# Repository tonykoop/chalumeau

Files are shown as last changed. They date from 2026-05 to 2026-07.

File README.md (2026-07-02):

# Chalumeau Family

Status: L2 V5 build-packet candidate. This is a prototype-validation scaffold
with parametric tables, starter CAD/drawings, presentation exports, and
measurement templates, but it is not a validated/build-ready or measured
chalumeau packet.

> Bare-bones readiness packet for a family of single-reed chalumeaux:
> keyless folk-pipe simplicity first, optional handmade two-key metalwork
> second, and a documented path toward clarinet-style register experiments.
> The current repo is a prototype-validation scaffold, not a build-ready or
> measured packet.

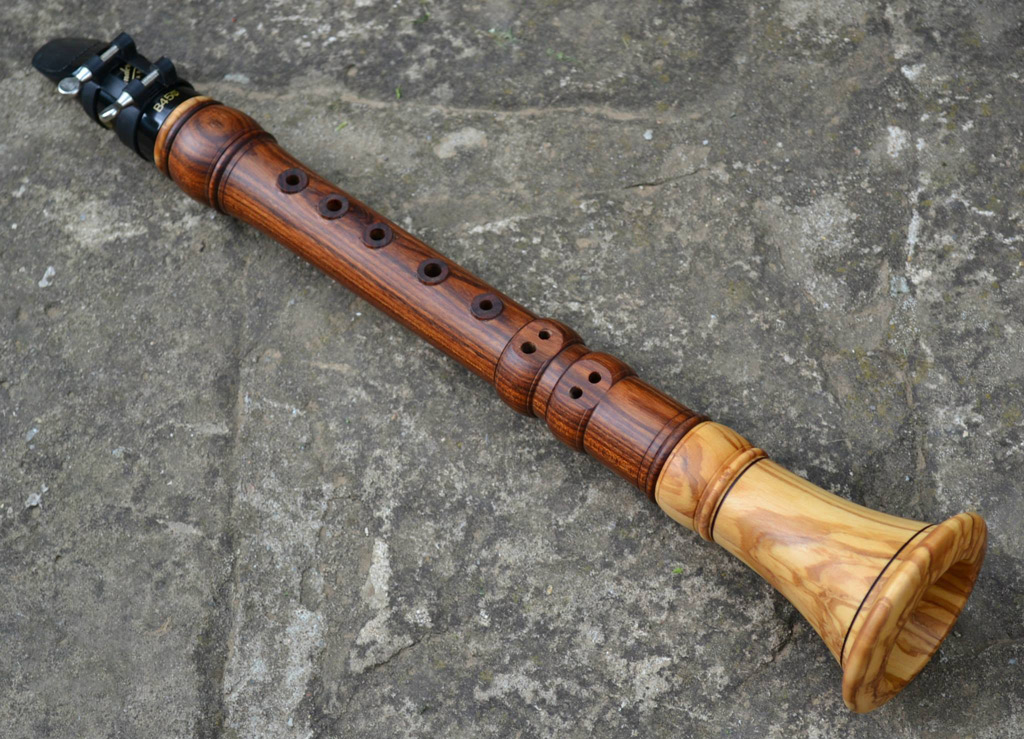
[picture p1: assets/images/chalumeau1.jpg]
Inspiration chalumeau with turned wood body, raised tone-hole collars, black mouthpiece, and flared bell

*Photo/reference instrument by Petr Skalicky / Dudy.eu, from
[dudy.eu/chalumeau.php](https://www.dudy.eu/chalumeau.php). Used here
as an attributed design reference, not as Tony's own build photo.*

## GitHub Repo Metadata

**Description:** Parametric build packet for a handmade chalumeau family,
including stopped-reed acoustics, tone-hole schedules, SolidWorks design
tables, and DIY keywork.

**Suggested topics:** `chalumeau`, `woodwind`, `single-reed`,
`clarinet-history`, `instrument-making`, `parametric-design`,
`solidworks`, `acoustic-modeling`, `cnc-lathe`, `woodworking`,
`music-technology`, `build-packet`

## What this is

This repository now contains a first-pass engineering packet for
designing and prototyping a family of chalumeaux in soprano C, alto G,
tenor C, and bass F. The design is parametric: body length, bore,
tone-hole positions, and optional levers are driven from formulas rather
than hidden one-off dimensions. It is not yet a build-ready or
empirically validated packet; the first soprano prototype still needs
measured reed, mouthpiece, bore, tuning, and response data.

The packet starts from attributed Dudy.eu chalumeau reference photos in
`assets/images/`, Tony's `Musical Instruments.xlsx` workbook, and especially
the reed/bore lessons in the `Great Highland Bagpipe` sheet. The
acoustic model is not copied from Native American style flute K2
corrections. A chalumeau is a cylindrical, single-reed, effectively
stopped pipe, so it gets its own validation loop.

## Family plan

| ID | Variant | Root | Bore ID | Final body L | Blank L | Sections |
| --- | --- | --- | --- | --- | --- | --- |
| CLM-SOP-C4 | Soprano C | C4 | 0.5 | 12.672 | 14.172 | 1 body + mouthpiece + bell |
| CLM-ALT-G3 | Alto G | G3 | 0.625 | 16.939 | 18.439 | 1 body + mouthpiece + bell |
| CLM-TEN-C3 | Tenor C | C3 | 0.75 | 25.483 | 26.983 | 2 body joints + mouthpiece + bell |
| CLM-BAS-F2 | Bass F | F2 | 0.875 | 38.32 | 39.82 | 3 body joints + mouthpiece + bell |

The recommended build order is `CLM-SOP-C4` first, with no levers, using
a commercial reed/mouthpiece. Once that speaks cleanly, add the two
optional levers to the same body or a second soprano body. Then scale up
to alto, tenor, and bass.

## Why some have levers

Keyless chalumeaux are mechanically close to folk reed pipes: finger
holes cover the notes that are reachable by hand. A few levers appear
when a useful tone hole is too low, too high, too large, or too awkward
to cover directly. The historical two-key chalumeau/early clarinet
moment is exactly that transition: keys first helped extend and smooth
the low register, then the clarinet moved one key into a better register
vent position and gradually accumulated more keys for chromatic notes,
trills, low extensions, and better intonation.

## Root starter packet

These root-level files are the review entry point for the current bare-bones
packet. They keep missing measurements and authority gaps visible before anyone
uses the deeper `build/` artifacts for shop work.

- [`design.md`](design.md) - current assumptions, acoustic boundary, evidence map, and promotion gates.
- [`bom.csv`](bom.csv) - starter material/components list with source and authority status.
- [`sourcing.csv`](sourcing.csv) - root procurement summary (condensed from `build/packet/sourcing.csv`).
- [`cut-list.csv`](cut-list.csv) - root per-variant blank/body cut summary (condensed from `build/packet/cut-list.csv`).
- [`drawing-brief.md`](drawing-brief.md) - root drawing-brief entry point (condensed from `build/packet/drawing-brief.md`).
- [`validation.csv`](validation.csv) - gates that must pass before L3/build-ready claims.
- [`risks.md`](risks.md) - acoustic, fabrication, sourcing, keywork, and documentation risks.
- [`photo-shotlist.md`](photo-shotlist.md) - future public-safe prototype documentation shots.
- [`capstone-manifest.json`](capstone-manifest.json) - root packet metadata and release gates.
- [`explorer.html`](explorer.html) - studio review surface for the packet, measurement loop, and capstone files.
- [`cad/chalumeau.scad`](cad/chalumeau.scad) - parametric bore-envelope +
  tone-hole-schedule OpenSCAD master for the soprano/alto/tenor/bass family;
  mouthpiece/reed/keywork are explicitly out of scope (see file header).
  `pending_measurement`, not fabrication authority.
- [`visual-output-register.csv`](visual-output-register.csv) - V5 authority
  register for existing CAD, drawing, presentation, image, and measurement
  artifacts.
- [`cad/mcp-session-log.md`](cad/mcp-session-log.md) - V5 provenance stub for
  this migration; no MCP/creative-tool session generated new artifacts here.
- [`evolution/`](evolution/) - Stage-0 evolution-pipeline intake (design
  intent, master manifest, revision register) for the current CAD/design-table
  masters; Gate A not yet run.
- [`qmd-step-0.md`](qmd-step-0.md) - Round 4 CLI retrieval record.

## Measurement capture loop

Issue #1 is the first measured-data gate. These files are templates, not
completed measurements:

- [`build/data/reed-mouthpiece-capture-template.csv`](build/data/reed-mouthpiece-capture-template.csv) - reed, mouthpiece, gap, onset, response, and leak setup capture.
- [`build/data/bore-trim-capture-template.csv`](build/data/bore-trim-capture-template.csv) - bore station, trim, all-closed pitch, and datum capture.
- [`build/data/prototype-measurement-template.csv`](build/data/prototype-measurement-template.csv) - prototype pitch/response sweep keyed to the same reed, mouthpiece, and bore IDs.
- [`build/data/tuning-capture-template.csv`](build/data/tuning-capture-template.csv) - tone-hole enlargement, cents error, response, and leak-check log.
- [`build/packet/validation-loop.md`](build/packet/validation-loop.md) - P0-P4 gates for moving from scaffold to measured prototype evidence.

## Existing build packet map

- [`build/packet/`](build/packet/) - design narrative, BOM, sourcing, cut list, validation loop, validation gates, assembly, RFQ, drawing/visual briefs, and Wolfram starter.
- [`build/presentation/`](build/presentation/) - capstone deck, printable packet, HTML/PDF exports, and manifest.
- [`build/design-tables/`](build/design-tables/) - Excel and SolidWorks-ready design tables.
- [`build/drawings/`](build/drawings/) - dimensioned drawing sheets and drawing exports.
- [`build/cad/`](build/cad/) - CAD/OpenSCAD/SolidWorks source and exports.
- [`build/cnc/`](build/cnc/) - CNC/CAM plans, setup sheets, fixtures, and toolpaths.
- [`build/hardware/`](build/hardware/) - handmade lever/keywork parts, guides, and hardware tables.
- [`assets/images/`](assets/images/) - photos, attributed references, concept art, and generated visuals.
- [`docs/`](docs/) - attribution, provenance, research, handoff notes, and reorganization manifest.

## V5 Authority Boundary

The current packet is reviewable at L2, not L3. `build/cad/`,
`build/drawings/`, `build/design-tables/`, and `build/presentation/` are useful
starter artifacts, but their dimensions and visual callouts still need shop
review, reed/mouthpiece setup records, prototype pitch/response captures, and
CAD/DXF authority review before any build-ready claim. The attributed photos
under `assets/images/` are reference images, not Tony shop photos or
dimensional evidence.

## Status

| Area | Status |
| --- | --- |
| Acoustic model | first-order stopped cylindrical reed model drafted; needs measured correction |
| Parametric family table | formula-derived scaffold, with SolidWorks export |
| Keywork concept | two-key handmade lever system specified |
| Manufacturing drawings | SVG first-pass sheets present; not reviewed fabrication authority |
| Shop build method | starter workflow for prototype review |
| Reed/tuning validation | capture templates and validation loop ready; needs measured prototype data |
| SolidWorks | variable conventions and design table ready |

## License

Released under [CC-BY 4.0](LICENSE) for original written/design content
in this repository. The Dudy.eu reference photos are attributed source
images, not Tony-owned build photos; replace them with shop photos as
prototypes are built.

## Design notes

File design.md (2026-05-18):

# Chalumeau Bare-Bones Starter Design

Current status: **bare-bones readiness packet / prototype-validation scaffold**.

Fabrication authority: **not build-ready**. The repo contains useful generated
packet artifacts under `build/`, including design tables, SVG drawing exports,
and OpenSCAD/SolidWorks starter files, but no measured prototype data or
reviewed CAD/DXF fabrication authority is present in this root packet.

## Intent

Create a reviewable repo-root entry point for the chalumeau family: a
cylindrical single-reed woodwind with keyless first-build emphasis and optional
two-key handmade metalwork after the soprano body speaks reliably.

The existing detailed packet lives in `build/packet/design.md`. This root
starter file does not replace that packet; it summarizes the current evidence
and the gates required before promoting the repo beyond scaffold status.

## Current Evidence

| Evidence | Location | Readiness note |
| --- | --- | --- |
| Family design narrative | `build/packet/design.md` | First-pass stopped-pipe model; requires measured correction. |
| Family dimensions and tables | `build/packet/family-spec.csv`, `build/design-tables/chalumeau-family-design-table.xlsx` | Formula-derived starting points, not measured build authority. |
| Tone-hole schedule | `build/data/tone-hole-schedule.csv` | Drill undersized; tune and log measured response before accepting. |
| CAD/OpenSCAD starters | `build/cad/` | Source/starter evidence only; no reviewed DXF or fabrication release. |
| Drawing previews | `build/drawings/` | Useful shop-review drawings; verify against measured prototype before build release. |
| Presentation packet | `build/presentation/` | Review/export surface; older manifest paths require root-level caution. |

## Acoustic Boundary

The chalumeau should be treated as a cylindrical single-reed stopped pipe in
the low register. The working first-pass model is:

```text
f = c / (4 * L_eff)
L_eff = c / (4 * f)
```

This packet does **not** apply Native American flute K2 corrections or
open-open flute assumptions. Reed/mouthpiece compliance, bore finish, tone-hole
chimney height, and player pressure require prototype measurement before any
tuning claim becomes validated.

`build/packet/family-spec.csv` now records `acoustic_law=stopped_pipe`,
`end_condition=one_end_closed_reed`, and
`dimension_provenance=measurement_required` for each family member. That keeps
the quarter-wave reed-pipe assumption explicit without pretending the current
lengths are empirically corrected build dimensions.

## Assumptions To Verify

| Assumption | Current value | Evidence needed |
| --- | --- | --- |
| Soprano C is the first prototype | assumption | Build-log decision and measured response. |
| Commercial reed/mouthpiece should be used first | assumption | Selected reed/mouthpiece model, strength, facing, and setup notes. |
| Tone-hole positions are starting points | derived estimate | Measured pitch sweep after drilling undersized holes. |
| Optional K01/K02 keywork can seal reliably | requires measurement | Leak-light/suction test and tuning data with pads installed. |
| Scaled alto/tenor/bass variants are viable | TBD | Soprano correction data before scaling. |

## Measurement Capture Files

The current measurement files are capture templates only. They become evidence
after shop measurements fill in the empty `measured_hz`, `cents_error`,
`onset_pressure_in_h2o`, `response_rating_1_5`, bore, gap, leak, and action
fields.

| Gate | Template | Blocks |
| --- | --- | --- |
| P0 reed/mouthpiece setup | `build/data/reed-mouthpiece-capture-template.csv` | root pitch claims |
| P1 bore/root tuning | `build/data/bore-trim-capture-template.csv` | final tone-hole drilling |
| P2 pitch/response sweep | `build/data/prototype-measurement-template.csv` and `build/data/tuning-capture-template.csv` | tone-hole acceptance and family scaling |
| P3 keywork seal | `validation.csv` plus shop leak evidence | keyed-note claims |

## Promotion Gates

The repo should stay at scaffold status until:

- the first soprano prototype has measured pitch/response data;
- reed and mouthpiece setup are recorded with each measurement pass;
- tone-hole changes are logged from undersized drilling through final tuning;
- keywork leak tests are documented if levers are installed;
- the chosen CAD/DXF/design-table artifact is declared as fabrication authority;
- sourcing rows are checked at purchase time, not treated as current quotes.

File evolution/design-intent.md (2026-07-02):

# Design Intent — chalumeau rev A

- Master CAD: `cad/chalumeau.scad` (sha256: 13451f99a86a681640b9e17f356b9698ee71d95884940ccebe95520e1bb521b9), driven by `build/packet/family-spec.csv` (sha256: 9ce0445943e6ebc0a44ed7502ac97fb6d3492f08f3095edcdd2c2f542a6a8b5a) and `build/data/tone-hole-schedule.csv` (sha256: 0f35e805d9f5326e0fc78a537e0cde939696324145dede14f72cae74ca83d0da)
- Function: cylindrical, single-reed, effectively stopped-pipe woodwind family in soprano C, alto G, tenor C, and bass F. Body length, bore ID, and tone-hole positions/diameters are formula/table-driven rather than one-off dimensions. First-pass acoustic law: `f = c / (4 * L_eff)` (design.md "Acoustic Boundary"). The recommended build order is soprano first, keyless, with a commercial reed/mouthpiece; optional two-key handmade lever hardware (K01/K02) may follow once the keyless body speaks reliably.
- Environment: indoor practice/prototype instrument; single-reed excitation, hand-held, no sustained structural load beyond finger/lever pressure on tone-hole covers.
- Target qty: 1 (soprano prototype). Deadline: TBD. Budget/unit ceiling: TBD.

## Critical dimensions (carry tolerances)

| Feature | Nominal (soprano CLM-SOP-C4) | Tolerance | Why critical | Source |
| --- | --- | --- | --- | --- |
| Bore ID | 0.500 in | +/- 0.003 in after ream/lap | sets stopped-pipe effective length and reed-seat fit | `build/packet/family-spec.csv` (measurement_required) |
| Body length (final) | 12.672 in | trim allowance; final by tuning | root pitch (C4, 261.63 Hz target) | `build/packet/family-spec.csv` (measurement_required) |
| Bell OD | 1.65 in | drawing/CAD review target | end-correction and foot flare geometry | `build/packet/family-spec.csv` (measurement_required) |
| Tone-hole X from bell (H01-H07, K01-K02) | 0.622-6.370 in (9 holes) | +/- 0.020 in first prototype | pitch of each scale degree/chromatic note | `build/data/tone-hole-schedule.csv` (measurement_required) |
| Tone-hole diameter (H01-H07, K01-K02) | 0.150-0.200 in | drilled undersize, opened during tuning | pitch and response of each note | `build/data/tone-hole-schedule.csv`, drill-undersize build_note |
| Wall thickness | 0.188 in | shop review | structural margin around tone holes/key posts | `build/packet/family-spec.csv` (measurement_required) |

## Incidental (free for DFM)

- Bell flare curve profile, exterior surface finish/turning texture, cosmetic collar/ring details, blank-to-final-length turning allowance (currently 1.5 in per `build/packet/cut-list.csv`).

## Must-nots (DFM may never violate)

- Do not treat `build/cad/`, `build/drawings/`, or `cad/chalumeau.scad` as reviewed fabrication authority — they are `pending_measurement` starter/source evidence until the soprano prototype's measured pitch/response data is folded back (risks.md R-BB-005; validation.csv VAL-BB-050).
- Do not drill tone holes to final diameter directly — start undersize (15-25%) and enlarge only against logged measured cents error (risks.md R-BB-002; tone-hole-schedule.csv build_note).
- Do not apply Native American flute (K2) or open-open flute end corrections — chalumeau is a cylindrical single-reed stopped pipe; keep `acoustic_law=stopped_pipe`, `end_condition=one_end_closed_reed` (design.md "Acoustic Boundary"; risks.md R-BB-003).
- Do not treat optional K01/K02 keywork as validated until leak-light/suction test passes with pads installed (risks.md R-BB-004; validation.csv VAL-BB-040).
- Do not model or fabricate mouthpiece/reed/reed-seat geometry from this CAD master — that geometry is explicitly out of scope and tuning-sensitive (cad/chalumeau.scad header; risks.md R-BB-001).

## Material intent

- Preferred: domestic hardwood prototype blanks (cherry, hard maple, or walnut) for the first soprano build (`bom.csv` CLM-BB-001; `build/packet/sourcing.csv`).
- Acceptable subs: dense keeper-build woods (ipe, cocobolo, boxwood, rosewood, grenadilla substitute) or Delrin/acetal for dimensional-stability testing, per `sourcing.csv`/`build/packet/sourcing.csv`.
- Forbidden: none recorded; oily/allergenic dense woods require dust control and finish tests before use (risks.md R-BB-006).

## Stage status

Stage 0 intake complete 2026-07-01. Gate A (Alpha shop compile) NOT yet run — no concessions logged, nothing presented as shippable or build-ready.

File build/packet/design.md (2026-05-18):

# CLM-001 - Chalumeau Family

Generated: 2026-05-03

## Intent

Design a family of chalumeaux that can be built in Tony's shop using
lathe/CNC workflows, commercial reeds for early isolation tests, and
optional handmade metal keywork. The family should cover a useful range
without pretending the first-pass physics is final: all tone-hole
coordinates are starting points that must be validated with a real reed,
mouthpiece, bore, and player pressure.

## Source Artifacts

- Repo: `https://github.com/tonykoop/chalumeau`
- Attributed inspiration/reference photos: `../../assets/images/chalumeau1.jpg` and
  `../../assets/images/chalumeau5.jpg`, from Petr Skalicky / Dudy.eu:
  `https://www.dudy.eu/chalumeau.php`
- Additional local inspiration image: `../../assets/images/7173-372-1_1920x1080.avif`
- Workbook inspected: `C:/Users/Tony/Documents/Claude/Projects/Career/flutes-staging/Musical Instruments.xlsx`
- Relevant workbook source sheet: `Great Highland Bagpipe`, especially the
  contrast between conical double-reed chanter rows and cylindrical
  single-reed drone rows.
- Done-bar reference style: `tongue-drum` repo packet and skill v3
  packet requirements.

## Governing Model

The chalumeau is modeled as a cylindrical single-reed pipe that behaves
like a stopped pipe in its low register.

```text
f = c / (4 * L_eff)
L_eff = c / (4 * f)
c = 13552 in/s at about 68 F
body_length = L_eff - bell_end_correction - reed_end_correction
bell_end_correction = 0.61 * bore_radius
reed_end_correction = 0.25 * bore_id   # first-pass assumption
tone_hole_x_from_bell = body_length - (c/(4*f_note) - reed_corr - 0.30*hole_dia)
cents_error = 1200 * log2(measured_hz / target_hz)
```

The model deliberately does not use Tony's NAF K2 corrections. Those
corrections are for open-open Native American style flutes in a specific
bore range. The chalumeau reed, stopped-pipe boundary condition,
mouthpiece volume, bore diameter, and tone-hole chimneys need their own
empirical correction after prototype measurement.

## Family Spec

| ID | Variant | Root | Bore ID | Final body L | Blank L | Sections |
| --- | --- | --- | --- | --- | --- | --- |
| CLM-SOP-C4 | Soprano C | C4 | 0.5 | 12.672 | 14.172 | 1 body + mouthpiece + bell |
| CLM-ALT-G3 | Alto G | G3 | 0.625 | 16.939 | 18.439 | 1 body + mouthpiece + bell |
| CLM-TEN-C3 | Tenor C | C3 | 0.75 | 25.483 | 26.983 | 2 body joints + mouthpiece + bell |
| CLM-BAS-F2 | Bass F | F2 | 0.875 | 38.32 | 39.82 | 3 body joints + mouthpiece + bell |

## Tone-Hole Strategy

- The keyless core uses seven front holes for a diatonic octave:
  offsets +2, +4, +5, +7, +9, +11, +12 semitones from the all-closed
  root.
- `K01` is an optional normally closed semitone key near the bell. It
  gives the first chromatic note above the root without forcing an
  awkward low finger stretch.
- `K02` is an optional upper chromatic side key. It gives a practical
  chromatic note between scale degrees 6 and 7 and doubles as a keywork
  fabrication exercise.
- A clarinet-style register vent is listed only as an experimental
  future feature. The first chalumeau should be judged by the low
  register before chasing overblown twelfths.

## Hardware Alignment

The hardware is intentionally small-shop manufacturable:

| Hardware | Role | First-build method | Upgrade path |
| --- | --- | --- | --- |
| K01 lever | opens low semitone tone hole | brass strip lever, pivot post pair, leather/cork pad | nickel-silver lever with soldered pad cup |
| K02 lever | opens upper chromatic tone hole | side lever with flat spring return | clarinet-style post/rod key with regulation cork |
| Optional register vent | tests clarinet evolution | leave undrilled until the body speaks well | small lined vent tube near mouthpiece |
| Raised tone-hole collars | ergonomic/aesthetic reference to photos | turn integral collars or add rings | separate stabilized-wood collars |

## SolidWorks Parameter Convention

Use `CLM_` as the project prefix, keep units in the variable name, and
use stable hole IDs that match the CSV and drawings:

- `CLM_Bore_ID_in`, `CLM_Body_L_Final_in`, `CLM_Bell_OD_in`
- `CLM_H01_X_Bell_in`, `CLM_H01_Dia_in`
- `CLM_K01_X_Bell_in`, `CLM_K01_Dia_in`
- `CLM_Key_Pivot_Rod_Dia_in`, `CLM_Pad_Overhang_in`

The SolidWorks design table is `../cad/solidworks-design-table.csv`. The
equation snippets are in `../cad/solidworks-equations.txt`.

## Assumptions And Risks

| Risk | Why it matters | Mitigation |
| --- | --- | --- |
| Reed/mouthpiece compliance shifts pitch | the reed is not a hard closed end | test with one commercial reed/mouthpiece before final hole tuning |
| Tone holes are first-pass estimates | small holes do not act as perfect open ends | drill undersized, tune larger, log every change |
| Bass holes exceed finger comfort | low instruments become large quickly | use key pads for lower/bigger holes |
| Handmade key pads leak | leaks ruin tuning and response | leak-light/suction test before pitch tuning |
| Dense oily woods complicate machining | cocobolo/ipe dust and finish issues | prototype in cherry/maple first |

## Validation Plan

1. Calibrate tuner/microphone at A4 = 440 Hz.
2. Build `CLM-SOP-C4` with no levers and a commercial reed/mouthpiece.
3. Tune the all-closed root by trimming the bell/foot only after reed
   response is stable.
4. Open holes from the bell upward, enlarging in small increments and
   logging measured frequency and cents error.
5. Add K01/K02 to either the same body or a second soprano body. Validate
   sealing before measuring pitch.
6. Fill `../data/reed-mouthpiece-capture-template.csv`,
   `../data/bore-trim-capture-template.csv`, and
   `../data/tuning-capture-template.csv` during the same measurement
   session so pitch data is tied to the actual reed, mouthpiece, bore,
   temperature, and blowing setup.
7. Update the empirical correction column in the design workbook before
   scaling to alto, tenor, or bass.

## Next Actions

- Confirm the actual reed and mouthpiece family for the soprano prototype.
- Run the Phase 0/1/2 gates in `validation-loop.md` before drilling final
  tone-hole diameters.
- Decide whether the first body gets raised collars like the inspiration
  image or plain chamfered holes for faster tuning.
- Model `CLM-SOP-C4` in SolidWorks using the provided global variables.
- After first measurements, add a `prototype_correction_pct` column to
  `../data/tone-hole-schedule.csv`.

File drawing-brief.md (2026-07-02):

# Chalumeau Drawing Brief (Root Starter)

Instrument: Chalumeau family
Revision/date: REV-A (root V5 refresh, 2026-07-01)
Units: inches unless noted
Source workbook/CAD/catalog ID: CLM-001 / SolidWorks design table

This root file is a condensed entry point. The detailed drawing brief lives at
[`build/packet/drawing-brief.md`](build/packet/drawing-brief.md); do not
duplicate dimensions here that would drift out of sync with that source.

## Required Views (summary)

- Family comparison side view with bore axis and body lengths (soprano, alto,
  tenor, bass).
- Soprano C dimensioned side view with all H/K hole coordinates.
- Cross-section through bore, tone-hole chimney, and raised collar.
- Keywork detail for K01/K02 (optional, two-key handmade lever system).
- Exploded view: mouthpiece/reed, body, bell, K01, K02, pads, posts.

## Authority Notes

- Bore ID, body length, and tone-hole positions/diameters are sourced from
  `build/packet/family-spec.csv` and `build/data/tone-hole-schedule.csv`
  (mirrored into `build/cad/solidworks-design-table.csv`). All values are
  `pending_measurement` / formula-derived starting points, not measured build
  authority.
- Mouthpiece, reed, and reed-table geometry are explicitly out of scope for
  this packet's CAD/drawing authority until reed/mouthpiece setup is selected
  and measured (see `risks.md` R-BB-001 and `validation.csv` VAL-BB-010).
- Hole X-from-bell tolerance target: +/- 0.020 in for the first prototype;
  holes are drilled undersize and opened during tuning.

## Drawing Outputs In This Packet

- `build/drawings/chalumeau-family-sheet.svg`
- `build/drawings/chalumeau-soprano-c4-dimensioned.svg`
- `build/drawings/keywork-lever-detail.svg`
- `cad/chalumeau.scad` — bore envelope + hole-schedule OpenSCAD master (added
  in this V5 refresh pass; mouthpiece/reed geometry out of scope, see header).

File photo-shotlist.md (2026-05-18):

# Chalumeau Photo Shotlist

Current status: **starter shotlist; no Tony-built prototype photos are present**.

Use this list for future public-safe documentation. Attributed reference photos
in `assets/images/` are source/provenance references, not finished build proof.

## Before Build

- Chosen reed and mouthpiece with labels visible.
- Selected prototype blank with ruler and grain orientation.
- Drill, reamer, and bore tooling setup before cutting.
- Printed or screen-visible tone-hole schedule marked `prototype / TBD`.

## During Build

- Bore drilling or reaming setup with workholding visible.
- First body after turning, before tone-hole drilling.
- Undersized tone holes before tuning enlargement.
- Tuner/microphone setup with temperature and humidity notes.
- Keyless first sound test setup.
- Optional K01/K02 keywork parts before installation, if used.
- Leak-light or suction-test setup for any installed keys.

## Validation

- All-closed root measurement with reed/mouthpiece setup documented.
- Tone-hole sweep after each tuning pass.
- Any wax/tape/temporary correction used during tuning.
- Final measured hole diameters after prototype tuning.

## Finished Review

- Side, front, and bell-end views of the completed prototype.
- Mouthpiece/reed close-up.
- Tone-hole and optional keywork close-ups.
- Known defects or revisions needed before the next body.

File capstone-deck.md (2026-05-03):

# Chalumeau Family Capstone
- Musical instrument documentation capstone
- Build packet: chalumeau
- Generated: 2026-05-03

---

# Project Intent
- Design a family of chalumeaux that can be built in Tony's shop using
lathe/CNC workflows, commercial reeds for early isolation tests, and
optional handmade metal keywork. The family should cover a useful range
without pretending the first-pass physics is final: all tone-hole
coordinates are starting points that must be validated with a real reed,
mouthpiece, bore, and player pressure.

_Speaker notes:_ Read design.md before committing to dimensions or sourcing decisions.

---

# Physics Model
- The chalumeau is modeled as a cylindrical single-reed pipe that behaves
like a stopped pipe in its low register.

```
f = c / (4 * L_eff)
L_eff = c / (4 * f)
c = 13552 in/s at about 68 F
body_length = L_eff - bell_end_correction - reed_end_correction
bell_end_correction = 0.61 * bore_radius
reed_end_correction = 0.25 * bore_id   # first-pass assumption
tone_hole_x_from_bell = body_length - (c/(4*f_note) - reed_corr - 0.30*hole_dia)
cents_error = 1200 * log2(measured_hz / target_hz)
```

_Speaker notes:_ Governing equations extracted verbatim from design.md. Apply empirical corrections (NAF K2, scale offsets) only where the model permits — see references/acoustic-models.md.

---

# Hardware Alignment
- The hardware is intentionally small-shop manufacturable:

| Hardware | Role | First-build method | Upgrade path |
| --- | --- | --- | --- |
| K01 lever | opens low semitone tone hole | brass strip lever, pivot post pair, leather/cork pad | nickel-silver lever with soldered pad cup |
| K02 lever | opens upper chromatic tone hole | side lever with flat spring return | clarinet-style post/rod key with regulation cork |
| Optional register vent | tests clarinet evolution | leave undrilled until the body speaks well | small lined vent tube near mouthpiece |
| Raised tone-hole collars | ergonomic/aesthetic reference to photos | turn integral collars or add rings | separate stabilized-wood collars |

_Speaker notes:_ Identifies which shop pipeline(s) this instrument lives in: Bambu+kiln slip-cast, 40W laser flat-pack, CNC+lathe, segmented turning, drum-skin work, or hybrid combinations.

---

# How To Use This Packet
- Start with design.md for intent and assumptions.
- Use bom.csv, sourcing.csv, and cut-list.csv before buying or cutting.
- Use drawing-brief.md and CAD/CNC folders before machining.
- Print the packet for shopping, shop work, and validation.

---

# File Map
- design.md: Project intent, catalog metadata, assumptions, and validation plan.
- bom.csv: Starter bill of materials with part categories, quantities, drawing refs, and notes.
- sourcing.csv: Supplier/search tracker with specs, price/date fields, lead time, substitutes, and risks.
- cut-list.csv: Rough/final stock sizes, material, grain/orientation, operations, yield, and offcuts.
- drawing-brief.md: Manufacturing drawing and technical product sketch brief.
- assembly-manual.md: Shop-facing sequence, tools, fixtures, safety, tuning, finishing, and maintenance notes.
- validation.csv: Target/measured values, tolerance, environment, result, and tuning/build action log.
- supplier-rfq.md: Supplier email/request-for-quote starter.

---

# Family Spec

| instrument_id | variant | root_note | root_midi | root_frequency_hz | bore_id_in | wall_thickness_in | body_od_in | bell_od_in | acoustic_length_in | body_length_final_in | blank_length_in | turning_blank_in | sections | build_priority | status |
| --- | --- | --- | --- | --- | --- | --- | --- | --- | --- | --- | --- | --- | --- | --- | --- |
| CLM-SOP-C4 | Soprano C | C4 | 60 | 261.63 | 0.5 | 0.188 | 0.875 | 1.65 | 12.95 | 12.672 | 14.172 | 1.25 x 1.25 x 14.172 | 1 body + mouthpiece + bell | Prototype 1 | first-order design; validate after reed and bore prototype |
| CLM-ALT-G3 | Alto G | G3 | 55 | 196.0 | 0.625 | 0.219 | 1.063 | 1.95 | 17.286 | 16.939 | 18.439 | 1.438 x 1.438 x 18.439 | 1 body + mouthpiece + bell | Prototype 2 | first-order design; validate after reed and bore prototype |
| CLM-TEN-C3 | Tenor C | C3 | 48 | 130.81 | 0.75 | 0.25 | 1.25 | 2.35 | 25.9 | 25.483 | 26.983 | 1.625 x 1.625 x 26.983 | 2 body joints + mouthpiece + bell | Prototype 3 | first-order design; validate after reed and bore prototype |
| CLM-BAS-F2 | Bass F | F2 | 41 | 87.31 | 0.875 | 0.313 | 1.5 | 2.9 | 38.806 | 38.32 | 39.82 | 1.875 x 1.875 x 39.82 | 3 body joints + mouthpiece + bell | Stretch prototype | first-order design; validate after reed and bore prototype |

_Speaker notes:_ Sizes scale via the master scale factor; tuning targets are first-order Helmholtz/cantilever predictions to be empirically corrected per prototype.

---

# Build Workflow
- Design and assumptions
- Source materials and hardware
- Prepare stock, fixtures, and CNC/laser/lathe setup
- Assemble, tune, finish, and validate

---

# Sourcing And BOM
- BOM gives part categories and drawing references.
- Sourcing tracks search terms, supplier candidates, price/date, lead time, substitutions.
- Visual BOM brief turns the parts list into a presentation-ready image board.

---

# Shop Packet
- Cut list for lumber/sheet/blank planning.
- Assembly manual for away-from-keyboard work.
- Validation sheet for measured dimensions, tuning, pass/fail checks.

---

# Drawings, CAD, CNC
- drawing-brief.md defines required views, dimensions, datums, sketch intent.
- cad/ holds models and design tables.
- cnc/ holds CAM, toolpaths, setup sheets, dry-run notes.
- drawings/ holds PDFs, SVGs, DXFs, drawing exports.





---

# Images And Screenshots
- images/chalumeau1.jpg
- images/chalumeau5.jpg


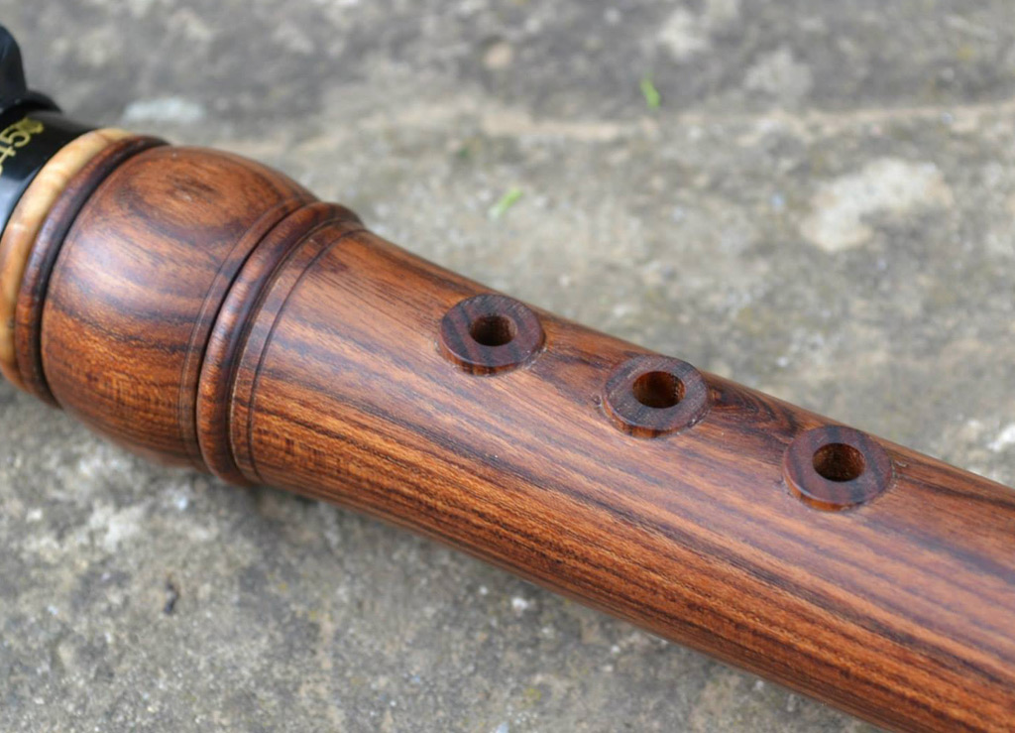
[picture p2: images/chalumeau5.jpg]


---

# Validation Plan
- A4 = 440 Hz reference check.
- Tuning targets logged in validation.csv.
- Critical dimensions verified against design sheet and CAD.
- Photos and revision notes after each major step.

---

# Open Risks / Decisions
- TBDs in design sheet and BOM.
- Supplier price/availability not yet verified.
- Generated images marked as concept placeholders.
- Empirical corrections await measured prototype data.

---

# Next Actions
- Replace TBDs with measured/source-backed values.
- Verify live supplier price and availability before buying.
- Export final drawings and visual BOM images.
- Regenerate this deck and print packet after final edits.

---

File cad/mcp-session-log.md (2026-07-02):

# MCP Session Log

No MCP, CAD, rendering, Illustrator, Photoshop, Blender, Fusion, or SolidWorks
session was run for the Round 4 V5 migration patch below. The 2026-07-01 V5
refresh pass (rows below) did run a local OpenSCAD CLI render-check on a new
codeCAD master; it did not run wolframscript (Wolfram stays source-only per
V5 honesty rules) and did not create measured tuning, reed/mouthpiece, or
prototype validation data.

The repo already contains generated or starter artifacts under `build/`,
including OpenSCAD/SolidWorks sources, SVG drawing previews, presentation
exports, and measurement templates. The Round 4 patch only added V5 authority
and provenance records; it did not create new CAD geometry, DXF coordinates,
measured tuning data, reed/mouthpiece data, or prototype validation.

| session_id | timestamp_utc | tool | input_authority | outputs | role | authority_result | review_status | notes |
| --- | --- | --- | --- | --- | --- | --- | --- | --- |
| r4-v5-migration-2026-05-30 | 2026-05-30 | none | README.md; design.md; build/packet/design.md; build/packet/drawing-brief.md; build/packet/visual-bom-brief.md | visual-output-register.csv; cad/mcp-session-log.md; README.md | provenance_stub | pending_measurement | self_checked | V5 register/status/provenance only; no fabricated CAD, DXF, acoustic, or measurement data. |
| fable-v5-refresh-2026-07-01 | 2026-07-01 | claude-code (Fable 5) | build/packet/family-spec.csv; build/data/tone-hole-schedule.csv; build/cad/solidworks-design-table.csv | bom.csv; sourcing.csv; cut-list.csv; drawing-brief.md; validation.csv | packet_refresh | fabrication | self_checked | V5 refresh pass; tabular packet data reviewed against design table (family-spec.csv, tone-hole-schedule.csv); root sourcing.csv/cut-list.csv/drawing-brief.md scaffolded honestly (TBD-marked) to satisfy required-baseline check, condensed from existing build/packet/ equivalents, no new dimensions invented. |
| fable-v5-refresh-2026-07-01 | 2026-07-01 | claude-code (Fable 5) + OpenSCAD CLI | build/packet/family-spec.csv; build/data/tone-hole-schedule.csv | cad/chalumeau.scad | cad_authoring | pending_measurement | self_checked | New parametric bore-envelope + tone-hole-schedule OpenSCAD master for all four family variants (soprano/alto/tenor/bass), values traced to family-spec.csv and tone-hole-schedule.csv. Mouthpiece, reed, reed-seat/tenor socket, tone-hole undercutting, and keywork are explicitly out of scope (see file header) — tuning-sensitive regions requiring hand refinement against a measured prototype. OpenSCAD render check: pass (openscad -o STL, exit 0, both default soprano render and SHOW_FAMILY=true four-variant layout). |
| fable-v5-refresh-2026-07-01 | 2026-07-01 | claude-code (Fable 5) | build/packet/chalumeau-packet-starter.wl | visual-output-register.csv (WL-001 row) | analysis_source | derived_preview | unreviewed | Existing Wolfram stopped-pipe first-pass acoustic model source; left as-is (not rewritten, not renamed). Not executed in this pass — source-only, L2 evidence per honesty rules. |

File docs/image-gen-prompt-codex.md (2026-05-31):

# Image Generation Prompt

Concept visualization only. Do not treat generated images as dimensional, tuning, CAD, DXF, or fabrication authority.

## Hero Prompt

Photorealistic studio product photograph of a finished handmade chalumeau family member, a cylindrical single-reed wooden folk pipe with a dark removable mouthpiece, warm turned hardwood body, subtle raised tone-hole collars, a gently flared bell, and optional simple two-key handmade brass leverwork mounted low on the body. Show the instrument as a real object on a clean neutral studio background, with visible finger holes, reed/mouthpiece socket, polished oil finish, small brass pivots and pads if keys are shown, realistic scale beside a folded linen cloth, soft directional studio lighting, three-quarter product-photography angle, about a 50mm lens, high detail, photorealistic.

## In-Context Prompt

Photorealistic image of the chalumeau resting on a tidy woodwind maker bench beside a tuner, spare reeds, calipers, a small notebook labeled with measurement rows but no readable text, and a few brass keywork blanks. Natural window light, shallow depth of field, workshop atmosphere, the instrument clearly readable as a keyless-first single-reed chalumeau with optional two-key hardware staged nearby, no fantasy ornament, no fabrication dimensions visible.

## Detail/Macro Prompt

Extreme close-up photorealistic macro of the chalumeau mouthpiece and upper tone-hole area: black single-reed mouthpiece seated into an oiled wooden cylindrical body, crisp tone-hole edges, one small handmade brass lever key and pad cup if included, subtle tool marks and waxed thread or cork at the joint, soft raking light emphasizing material texture, very high detail.

## Negative / Avoid

Avoid logos, watermarks, readable text, impossible key mechanisms, extra holes, extra reeds, saxophone/clarinet modern keywork, distorted bores, and anatomically implausible hands.

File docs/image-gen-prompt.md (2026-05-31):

# Image-Gen Prompts

Concept image only; not fabrication authority. Do not include cut-ready dimensions, hole locations, or toolpaths.

## Hero Prompt

A single finished soprano chalumeau presented as a real physical object: a slender, straight cylindrical single-reed folk pipe turned from warm close-grained hardwood, with a gently raised collar ringed around each finger tone hole along the front face and a row of evenly spaced holes that read as hand-reachable. One end carries a separate dark mouthpiece holding a flat cane single reed bound on with a clamp, and the opposite end opens into a modest turned flared bell of the same wood. The body shows subtle lathe-turned beading at the section joints between mouthpiece, body, and bell, hinting at the keyless first-build design before any metal levers are added. Surface is a satin oiled wood finish with visible natural grain, neutral seamless studio background, soft directional studio light grazing the body to reveal the tone-hole collars and turning detail, 3/4 product-photography angle, ~50mm lens, realistic table-scale proportions for a clarinet-relative woodwind, high detail, photorealistic, no text labels.

## In-Context Prompt

The same soprano chalumeau resting on a maker's workbench in a small wood shop, lying beside a coil of reed cane and a turned blank, with a lathe and hand tools softly blurred in the background; warm natural window light rakes across the oiled wood body and the raised tone-hole collars, shallow depth of field keeping the mouthpiece reed and front holes sharp while the shop falls into bokeh; environmental storytelling of a handmade folk-pipe prototype, concept visualization only, no text labels.

## Detail Prompt

Macro close-up of the chalumeau's dark mouthpiece and signature raised tone-hole collars: the flat cane single reed seated against the mouthpiece table and held by its clamp, transitioning into the cylindrical wood body where two or three turned collars rise around their finger holes, raking side light emphasizing the satin grain, the bevel of each collar, and the bound reed fibers; high detail, photorealistic, no measurements.

## Negative / Avoid

No text, logos, watermarks, or fake maker marks; no dimension callouts or measurement lines; no impossible mechanisms or floating keys; if a player is shown, anatomically plausible hands with fingers that plausibly cover the holes.

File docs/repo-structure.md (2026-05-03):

# Repository Structure

This repo uses the lean instrument-folder layout documented in [instrument-maker/docs/instrument-repo-folder-template.md](../../instrument-maker/docs/instrument-repo-folder-template.md). The goal is to keep the GitHub root short enough that the README preview is visible immediately.

```text
chalumeau/
├── README.md                   # first-reader overview
├── LICENSE
├── assets/                     # images, thumbnails, recordings
├── build/                      # packet, presentation, CAD/CNC, drawings, data
├── docs/                       # attribution, provenance, research, manifests
├── tools/                      # repo-specific generators or analysis scripts
└── .gitignore
```

The full move history for this layout is tracked in [`reorg-manifest.json`](reorg-manifest.json).

## Build Packet Locations

- [`../build/packet/`](../build/packet/) - design narrative, BOM, sourcing, cut list, validation, assembly, RFQ, drawing/visual briefs, and Wolfram starter.
- [`../build/presentation/`](../build/presentation/) - capstone deck, printable packet, HTML/PDF exports, and manifest.
- [`../build/design-tables/`](../build/design-tables/) - Excel and SolidWorks-ready design tables.
- [`../build/drawings/`](../build/drawings/) - dimensioned drawing sheets and drawing exports.
- [`../build/cad/`](../build/cad/) - CAD/OpenSCAD/SolidWorks source and exports.
- [`../build/cnc/`](../build/cnc/) - CNC/CAM plans, setup sheets, fixtures, and toolpaths.
- [`../build/hardware/`](../build/hardware/) - handmade lever/keywork parts, guides, and hardware tables.
- [`../assets/images/`](../assets/images/) - photos, attributed references, concept art, and generated visuals.
- [`./`](./) - attribution, provenance, research, handoff notes, and reorganization manifest.

## Migration Note

No source files were intentionally deleted in this reorganization. Moved paths are recorded in `reorg-manifest.json`.

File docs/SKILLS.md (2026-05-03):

# Skills Demonstrated

## stopped-cylindrical-reed-bore

Models a single-reed cylindrical bore as a stopped pipe in the low
register, with explicit reed and bell end-correction assumptions.

## handmade-woodwind-keywork

Designs and fabricates simple early-woodwind levers using brass or
nickel silver, pivot rods, pads, posts, and springs.

## solidworks-parametric-family-table

Uses one design table to drive multiple instrument-family
configurations, with stable named dimensions that match CSV, drawings,
and validation logs.

## empirical-tone-hole-validation

Starts with physics-derived hole positions, then tunes the real
prototype by measured frequency and cents error rather than trusting the
first-pass model blindly.

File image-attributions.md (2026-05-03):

# Image Attributions

## Dudy.eu Chalumeau Reference Photos

- `images/chalumeau1.jpg`
- `images/chalumeau5.jpg`

Attribution: Petr Skalicky / Dudy.eu, chalumeau reference page:
https://www.dudy.eu/chalumeau.php

Use in this repo: attributed visual reference for form, finish, raised
tone-hole collars, mouthpiece layout, and bell styling. These are not Tony's
own build photos.

## Additional Local Inspiration Image

- `images/7173-372-1_1920x1080.avif`

Attribution/source: TBD. Keep as local inspiration only until provenance is
confirmed or replace with shop-generated imagery.

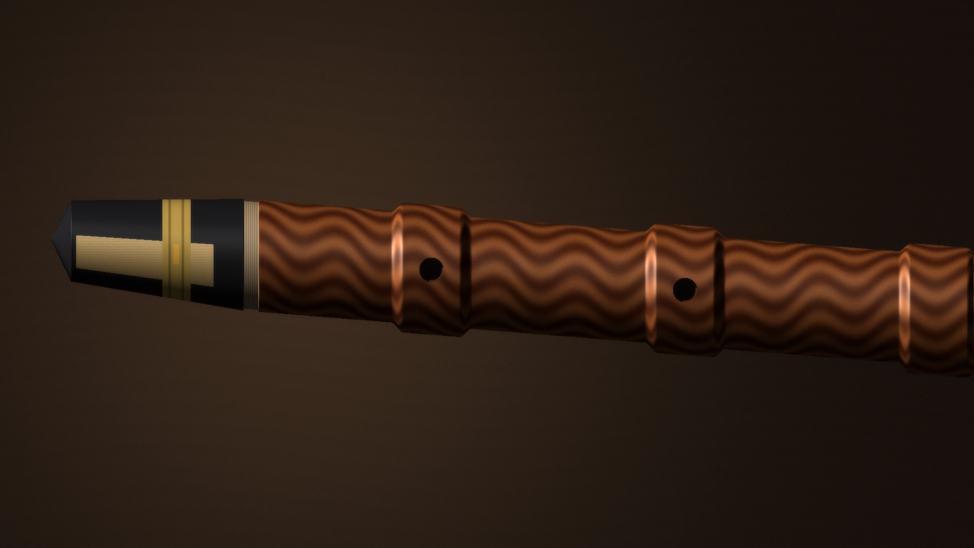
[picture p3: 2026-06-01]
images/macro/reed-mouthpiece-tonehole-collars.png

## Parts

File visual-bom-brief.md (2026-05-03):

# Visual BOM Brief

## Layout

Use the Ashiko visual BOM pattern: hero image at the top, spreadsheet
rows below, and one part image/render per row. Use the actual local
chalumeau photos for the hero/inspiration image until Tony has shop
photos of the prototypes.

## Real Images Available

- `images/chalumeau1.jpg`: full instrument inspiration, attributed to
  Petr Skalicky / Dudy.eu, `https://www.dudy.eu/chalumeau.php`.
- `images/chalumeau5.jpg`: close-up of raised collars and wood finish,
  attributed to Petr Skalicky / Dudy.eu, `https://www.dudy.eu/chalumeau.php`.
- `images/7173-372-1_1920x1080.avif`: additional inspiration image,
  not universally supported by all renderers.

## Part Rows To Show

1. Turned body blank.
2. Mouthpiece/reed assembly.
3. Bell.
4. H01-H07 tone-hole row with raised collars.
5. K01 low semitone lever.
6. K02 side chromatic lever.
7. Pad/cork/felt stack.
8. Pivot posts, rods, springs, screws.
9. Finish and bore oil.

## Placeholder Policy

Generated or schematic part images are acceptable for planning, but mark
them as placeholders until replaced with supplier images or shop photos.
Build-critical dimensions must come from the CSV/workbook/SolidWorks,
not from pixels in the visual BOM.

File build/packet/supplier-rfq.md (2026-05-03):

# Supplier RFQ - Chalumeau Materials And Keywork

Hello,

I am sourcing materials for a small family of handmade single-reed
chalumeaux. Please quote the items below, including unit price, volume
price if applicable, lead time, shipping estimate, and any recommended
substitutes.

## Wood Or Plastic Blanks

- Straight-grain turning blanks suitable for woodwind bodies.
- Prototype species: cherry, hard maple, walnut, or Delrin/acetal.
- Keeper species: ipe, boxwood, cocobolo, rosewood, or grenadilla
  substitute.
- Sizes range from about 1.25 x 1.25 x 15 in to 2.25 x 2.25 x 41 in.
  Exact dimensions are in `cut-list.csv`.

## Keywork Materials

- Brass or nickel-silver sheet, 0.040-0.062 in thick.
- 1/16 in rod or equivalent pivot stock.
- Small screws, post stock, and phosphor bronze spring wire.
- Clarinet/sax pads or pad leather/cork materials.

## Requirements

- Material must be stable, dry, and suitable for fine drilling/turning.
- Please identify any allergy/dust or finish compatibility concerns.
- Substitutions are acceptable if dimensional stability and machinability
  are comparable.

Thank you.

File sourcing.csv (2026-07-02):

item_id | subsystem | item | required_spec | supplier_candidates | date_checked | unit_price | lead_time | substitution_risk | authority_note | next_action
CLM-SRC-001 | body | domestic hardwood prototype turning blanks | straight-grain cherry/hard maple/walnut; 1.5-2.25 in square; length per family-spec.csv | local hardwood dealer; Bell Forest; Cook Woods; Woodcraft | not live-checked | research before purchase | research before purchase | Low | Full detail in build/packet/sourcing.csv row 1 | Select domestic hardwood and record actual blank dimensions
CLM-SRC-002 | body | dense keeper-build blanks | ipe, cocobolo, boxwood, rosewood, grenadilla substitute; dry and crack-free | Gilmer Wood; Cook Woods; Bell Forest; specialty woodwind blank suppliers | not live-checked | research before purchase | research before purchase | Medium | Full detail in build/packet/sourcing.csv row 2; oily/allergenic woods need dust control | Buy only after soprano keyless prototype validates process
CLM-SRC-003 | reed | single reeds and mouthpieces | soprano/alto use clarinet-like reeds; tenor/bass may use sax/low clarinet reeds or custom mouthpiece | woodwind suppliers; early-music makers; 3D print/Delrin shop-made option | not live-checked | research before purchase | research before purchase | Medium | Full detail in build/packet/sourcing.csv row 3; reed strength/mouthpiece volume shift pitch and response | Select one commercial reed/mouthpiece to decouple reed-making from bore tuning
CLM-SRC-004 | keywork | brass/nickel-silver key stock | 0.040-0.062 in sheet, 1/16 in rod, 0-80 or M1.6 screws, post stock | McMaster-Carr; K&S metals; MusicMedic; instrument repair suppliers | not live-checked | research before purchase | research before purchase | Low | Full detail in build/packet/sourcing.csv row 4; optional, keyless body first | Build only after keyless body speaks reliably
CLM-SRC-005 | keywork | pads/cork/felt/leather | clarinet/sax pads or leather-over-cork pads sized to K01/K02 tone holes | MusicMedic; Ferree's Tools; instrument repair suppliers | not live-checked | research before purchase | research before purchase | Low | Full detail in build/packet/sourcing.csv row 5 | Source after key posts and lever geometry are fixed by CAD review

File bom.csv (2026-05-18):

item_id | subsystem | item | qty | status | source_status | authority_note | next_action
CLM-BB-001 | body | prototype hardwood blank for soprano C | 1 | planned | supplier-unverified | Dimensions derive from build/packet/family-spec.csv and require shop confirmation | Select domestic hardwood and record actual blank dimensions
CLM-BB-002 | bore | long drill/reamer tooling for soprano bore | 1 | planned | supplier-unverified | Tooling path is not validated on a physical blank | Choose drilling/reaming method and test on scrap
CLM-BB-003 | reed | mouthpiece and commercial reed set | 1 | planned | supplier-unverified | Reed/mouthpiece setup controls pitch and response but is not selected yet | Record model plus reed strength plus facing and setup notes
CLM-BB-004 | tone_holes | undersized tone-hole drilling process | 1 | planned | shop-process-required | Hole positions are first-pass estimates only | Drill undersized and log measured tuning changes
CLM-BB-005 | keywork | optional K01/K02 lever hardware | 1 | optional | supplier-unverified | Optional keywork is source/starter evidence and not validated metalwork | Build only after keyless body speaks reliably
CLM-BB-006 | documentation | measurement log and prototype photos | 1 | missing | measurement-required | No measured Tony-built prototype evidence is present | Capture pitch plus response plus leak and build photos during first prototype

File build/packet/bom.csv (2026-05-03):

item_no | subsystem | part_name | qty | material_spec | dimensions_spec | make_buy | estimated_cost | drawing_ref | notes
1 | Body | Turned chalumeau body blanks | 4 | Cherry or hard maple for first pass; ipe/cocobolo/boxwood for keeper builds | see family-spec.csv blank_length_in and turning_blank_in | make | 80 | drawings/chalumeau-family-sheet.svg | Use lower-cost domestic hardwood for bore and keywork tests before dense/oily woods.
2 | Bore | Long drill and reamer set | 1 | Aircraft-length brad point/twist drills plus adjustable/shell reamers | 0.500, 0.625, 0.750, 0.875 in bore targets | buy | 120 | cnc/cnc-lathe-plan.md | Exact tooling depends on whether bores are drilled solid or routed as split blanks.
3 | Mouthpiece | Single-reed mouthpieces | 4 | Purchased clarinet/sax mouthpiece adapted by size, or shop-made Delrin mouthpiece | socket IDs in family-spec.csv; reed table in design.md | buy first, make later | 160 | drawing-brief.md | Use bought mouthpieces/reeds to isolate body acoustics before making reeds.
4 | Tone holes | Raised tone-hole collars or drilled holes | 36 | Integral turned collars for visual style; chamfered holes for first prototype | see data/tone-hole-schedule.csv | make | 20 | drawings/chalumeau-soprano-c4-dimensioned.svg | Collars are visual and ergonomic; pitch comes from hole center, diameter, and chimney.
5 | Keywork | Two-key chalumeau lever set | 4 | 0.040-0.062 in brass/nickel silver sheet, 1/16 in pivot rod, phosphor bronze spring | K01 and K02 per variant; see hardware/keywork-parts.csv | make | 60 | drawings/keywork-lever-detail.svg | The first soprano can be built keyless, then retrofitted with keys.
6 | Pads | Leather/cork/felt pad stack | 12 | Clarinet-style skin pads or cork backed with thin leather | pad OD = tone hole OD + 0.080 to 0.125 in | buy or make | 35 | hardware/lever-fabrication-guide.md | Use leak light or suction test before tuning.
7 | Finish | Oil/shellac finish and bore oil | 1 | Dewaxed shellac outside; bore oil compatible with chosen wood | finish schedule in assembly-manual.md | buy | 30 | assembly-manual.md | Avoid thick finish buildup inside tone holes or under pads.

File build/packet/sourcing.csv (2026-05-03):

component | required_spec | search_terms | supplier_candidates | date_checked | unit_price | lead_time | substitute_rule | risk_notes
Domestic hardwood prototype blanks | Straight-grain cherry, hard maple, or walnut; 1.5-2.25 in square; length per family-spec.csv | turning blank cherry hard maple 2x2x18 2x2x30 | local hardwood dealer, Bell Forest, Cook Woods, Woodcraft | not live-checked | research before purchase | research before purchase | Any stable fine-grained hardwood is acceptable for first acoustic prototypes. | Soft woods dent around tone holes and key posts; use for process tests only.
Dense keeper-build blanks | Ipe, cocobolo, boxwood, rosewood, grenadilla substitute; dry and crack-free | ipe turning blank cocobolo clarinet blank boxwood woodwind blank | Gilmer Wood, Cook Woods, Bell Forest, specialty woodwind blank suppliers | not live-checked | research before purchase | research before purchase | Delrin/acetal is acceptable for dimensional-stability testing. | Allergenic/oily woods need dust control, wiping before glue, and finish tests.
Single reeds and mouthpieces | Soprano/alto use clarinet-like reeds; tenor/bass may use sax/low clarinet reeds or custom mouthpiece | clarinet mouthpiece blank baroque clarinet reed tenor chalumeau mouthpiece | woodwind suppliers, early-music makers, 3D print/Delrin shop-made option | not live-checked | research before purchase | research before purchase | Use commercial reed first to decouple reed-making from bore tuning. | Reed strength and mouthpiece volume can shift pitch and response significantly.
Brass/nickel-silver key stock | 0.040-0.062 in sheet, 1/16 in rod, 0-80 or M1.6 screws, post stock | nickel silver sheet woodwind key rod phosphor bronze spring wire | McMaster-Carr, K&S metals, MusicMedic, instrument repair suppliers | not live-checked | research before purchase | research before purchase | Brass is easier to prototype; nickel silver wears better and solders cleanly. | Tiny screws strip easily; buy extras and make drill guides.
Pads, cork, felt, leather | Clarinet/sax pads or leather-over-cork pads sized to K01/K02 tone holes | clarinet pads sheet cork felt key bumper leather pad cup | MusicMedic, Ferree's Tools, instrument repair suppliers | not live-checked | research before purchase | research before purchase | Cork plus thin leather is acceptable for first handmade keys. | Pad seating matters more than pad material for early prototypes.

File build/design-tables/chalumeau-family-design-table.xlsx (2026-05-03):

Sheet: Family Spec
Chalumeau Family Parametric Design Table
Input | Unit | Value | Notes
Speed of sound | in/s | 13552 | blue input; adjust for temperature
Bell end correction factor | radius multiple | 0.61 | open-end first pass
Reed end correction factor | bore ID multiple | 0.25 | first-pass reed/mouthpiece compliance
Instrument ID | Variant | Root MIDI | Bore ID in | Wall in | Root Hz | Acoustic L in | Body L final in | Blank L in | Body OD in | Bell OD in
CLM-SOP-C4 | Soprano C | 60 | 0.5 | 0.1875 |  |  |  |  |  | 1.65
CLM-ALT-G3 | Alto G | 55 | 0.625 | 0.21875 |  |  |  |  |  | 1.95
CLM-TEN-C3 | Tenor C | 48 | 0.75 | 0.25 |  |  |  |  |  | 2.35
CLM-BAS-F2 | Bass F | 41 | 0.875 | 0.3125 |  |  |  |  |  | 2.9

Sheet: Tone Holes
Tone Hole Schedule
Variant ID | Hole ID | Offset | Note | Target Hz | Hole Dia in | X From Bell in | Control | Tier
CLM-SOP-C4 | K01 | 1 | C#4 | 277.18 | 0.16 | 0.622 | normally closed lever | two-key historical option
CLM-SOP-C4 | H01 | 2 | D4 | 293.66 | 0.18 | 1.314 | RH little finger | keyless core
CLM-SOP-C4 | H02 | 4 | E4 | 329.63 | 0.19 | 2.576 | RH ring finger | keyless core
CLM-SOP-C4 | H03 | 5 | F4 | 349.23 | 0.17 | 3.147 | RH middle finger | keyless core
CLM-SOP-C4 | H04 | 7 | G4 | 392 | 0.19 | 4.211 | RH index finger | keyless core
CLM-SOP-C4 | H05 | 9 | A4 | 440 | 0.2 | 5.157 | LH ring finger | keyless core
CLM-SOP-C4 | K02 | 10 | Bb4 | 466.16 | 0.15 | 5.574 | normally closed side lever | two-key historical option
CLM-SOP-C4 | H06 | 11 | B4 | 493.88 | 0.17 | 5.988 | LH middle finger | keyless core
CLM-SOP-C4 | H07 | 12 | C5 | 523.25 | 0.16 | 6.37 | LH index finger | keyless core
CLM-ALT-G3 | K01 | 1 | Ab3 | 207.65 | 0.2 | 0.84 | normally closed lever | two-key historical option
CLM-ALT-G3 | H01 | 2 | A3 | 220 | 0.225 | 1.763 | RH little finger | keyless core
CLM-ALT-G3 | H02 | 4 | B3 | 246.94 | 0.238 | 3.447 | RH ring finger | keyless core
CLM-ALT-G3 | H03 | 5 | C4 | 261.63 | 0.213 | 4.209 | RH middle finger | keyless core
CLM-ALT-G3 | H04 | 7 | D4 | 293.66 | 0.238 | 5.63 | RH index finger | keyless core
CLM-ALT-G3 | H05 | 9 | E4 | 329.63 | 0.25 | 6.892 | LH ring finger | keyless core
CLM-ALT-G3 | K02 | 10 | F4 | 349.23 | 0.188 | 7.45 | normally closed side lever | two-key historical option
CLM-ALT-G3 | H06 | 11 | F#4 | 369.99 | 0.213 | 8.002 | LH middle finger | keyless core
CLM-ALT-G3 | H07 | 12 | G4 | 392 | 0.2 | 8.512 | LH index finger | keyless core
CLM-TEN-C3 | K01 | 1 | C#3 | 138.59 | 0.24 | 1.297 | normally closed lever | two-key historical option
CLM-TEN-C3 | H01 | 2 | D3 | 146.83 | 0.27 | 2.678 | RH little finger | keyless core
CLM-TEN-C3 | H02 | 4 | E3 | 164.81 | 0.285 | 5.2 | RH ring finger | keyless core
CLM-TEN-C3 | H03 | 5 | F3 | 174.61 | 0.255 | 6.345 | RH middle finger | keyless core
CLM-TEN-C3 | H04 | 7 | G3 | 196 | 0.285 | 8.47 | RH index finger | keyless core
CLM-TEN-C3 | H05 | 9 | A3 | 220 | 0.3 | 10.361 | LH ring finger | keyless core
CLM-TEN-C3 | K02 | 10 | Bb3 | 233.08 | 0.225 | 11.203 | normally closed side lever | two-key historical option
CLM-TEN-C3 | H06 | 11 | B3 | 246.94 | 0.255 | 12.028 | LH middle finger | keyless core
CLM-TEN-C3 | H07 | 12 | C4 | 261.63 | 0.24 | 12.793 | LH index finger | keyless core
CLM-BAS-F2 | K01 | 1 | F#2 | 92.5 | 0.28 | 1.995 | normally closed lever | two-key historical option
CLM-BAS-F2 | H01 | 2 | G2 | 98 | 0.315 | 4.061 | RH little finger | keyless core
CLM-BAS-F2 | H02 | 4 | A2 | 110 | 0.333 | 7.838 | RH ring finger | keyless core
CLM-BAS-F2 | H03 | 5 | Bb2 | 116.54 | 0.298 | 9.557 | RH middle finger | keyless core
CLM-BAS-F2 | H04 | 7 | C3 | 130.81 | 0.333 | 12.739 | RH index finger | keyless core
CLM-BAS-F2 | H05 | 9 | D3 | 146.83 | 0.35 | 15.57 | LH ring finger | keyless core
CLM-BAS-F2 | K02 | 10 | Eb3 | 155.56 | 0.263 | 16.839 | normally closed side lever | two-key historical option
CLM-BAS-F2 | H06 | 11 | E3 | 164.81 | 0.298 | 18.071 | LH middle finger | keyless core
CLM-BAS-F2 | H07 | 12 | F3 | 174.61 | 0.28 | 19.22 | LH index finger | keyless core

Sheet: Keywork
Keywork Levers
part_id | variant | key_function | tone_hole_note | tone_hole_dia_in | pad_od_in | lever_length_in | pivot_rod_in | sheet_thickness_in | spring | default_state | drawing_ref
CLM-SOP-C4-K01 | Soprano C | root sharp semitone | C#4 | 0.16 | 0.27 | 1.75 | 0.0625 | 0.050 | 0.012-0.018 in phosphor bronze needle or flat spring | closed pad; press lever to open | drawings/keywork-lever-detail.svg
CLM-SOP-C4-K02 | Soprano C | upper chromatic | Bb4 | 0.15 | 0.26 | 4.5 | 0.0625 | 0.050 | 0.012-0.018 in phosphor bronze needle or flat spring | closed pad; press lever to open | drawings/keywork-lever-detail.svg
CLM-ALT-G3-K01 | Alto G | root sharp semitone | Ab3 | 0.2 | 0.31 | 1.75 | 0.0625 | 0.050 | 0.012-0.018 in phosphor bronze needle or flat spring | closed pad; press lever to open | drawings/keywork-lever-detail.svg
CLM-ALT-G3-K02 | Alto G | upper chromatic | F4 | 0.188 | 0.298 | 4.5 | 0.0625 | 0.050 | 0.012-0.018 in phosphor bronze needle or flat spring | closed pad; press lever to open | drawings/keywork-lever-detail.svg
CLM-TEN-C3-K01 | Tenor C | root sharp semitone | C#3 | 0.24 | 0.35 | 2.047 | 0.0625 | 0.050 | 0.012-0.018 in phosphor bronze needle or flat spring | closed pad; press lever to open | drawings/keywork-lever-detail.svg
CLM-TEN-C3-K02 | Tenor C | upper chromatic | Bb3 | 0.225 | 0.335 | 4.5 | 0.0625 | 0.050 | 0.012-0.018 in phosphor bronze needle or flat spring | closed pad; press lever to open | drawings/keywork-lever-detail.svg
CLM-BAS-F2-K01 | Bass F | root sharp semitone | F#2 | 0.28 | 0.39 | 2.745 | 0.0625 | 0.050 | 0.012-0.018 in phosphor bronze needle or flat spring | closed pad; press lever to open | drawings/keywork-lever-detail.svg
CLM-BAS-F2-K02 | Bass F | upper chromatic | Eb3 | 0.263 | 0.373 | 4.5 | 0.0625 | 0.050 | 0.012-0.018 in phosphor bronze needle or flat spring | closed pad; press lever to open | drawings/keywork-lever-detail.svg

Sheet: SolidWorks Export
SolidWorks Export
$CONFIGURATION | $DESCRIPTION | CLM_Root_MIDI | CLM_Root_Hz | CLM_SOS_in_per_s | CLM_Bore_ID_in | CLM_Wall_T_in | CLM_Body_OD_in | CLM_Bell_OD_in | CLM_Body_L_Final_in | CLM_Blank_L_in | CLM_K01_X_Bell_in | CLM_K01_Dia_in | CLM_H01_X_Bell_in | CLM_H01_Dia_in | CLM_H02_X_Bell_in | CLM_H02_Dia_in | CLM_H03_X_Bell_in | CLM_H03_Dia_in | CLM_H04_X_Bell_in | CLM_H04_Dia_in | CLM_H05_X_Bell_in | CLM_H05_Dia_in | CLM_K02_X_Bell_in | CLM_K02_Dia_in | CLM_H06_X_Bell_in | CLM_H06_Dia_in | CLM_H07_X_Bell_in | CLM_H07_Dia_in
CLM-SOP-C4 | Soprano C | 60 | 261.63 | 13552.0 | 0.5 | 0.188 | 0.875 | 1.65 | 12.672 | 14.172 | 0.622 | 0.16 | 1.314 | 0.18 | 2.576 | 0.19 | 3.147 | 0.17 | 4.211 | 0.19 | 5.157 | 0.2 | 5.574 | 0.15 | 5.988 | 0.17 | 6.37 | 0.16
CLM-ALT-G3 | Alto G | 55 | 196.0 | 13552.0 | 0.625 | 0.219 | 1.063 | 1.95 | 16.939 | 18.439 | 0.84 | 0.2 | 1.763 | 0.225 | 3.447 | 0.238 | 4.209 | 0.213 | 5.63 | 0.238 | 6.892 | 0.25 | 7.45 | 0.188 | 8.002 | 0.213 | 8.512 | 0.2
CLM-TEN-C3 | Tenor C | 48 | 130.81 | 13552.0 | 0.75 | 0.25 | 1.25 | 2.35 | 25.483 | 26.983 | 1.297 | 0.24 | 2.678 | 0.27 | 5.2 | 0.285 | 6.345 | 0.255 | 8.47 | 0.285 | 10.361 | 0.3 | 11.203 | 0.225 | 12.028 | 0.255 | 12.793 | 0.24
CLM-BAS-F2 | Bass F | 41 | 87.31 | 13552.0 | 0.875 | 0.313 | 1.5 | 2.9 | 38.32 | 39.82 | 1.995 | 0.28 | 4.061 | 0.315 | 7.838 | 0.333 | 9.557 | 0.298 | 12.739 | 0.333 | 15.57 | 0.35 | 16.839 | 0.263 | 18.071 | 0.298 | 19.22 | 0.28

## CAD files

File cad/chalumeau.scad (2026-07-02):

// Chalumeau family — bore envelope + tone-hole schedule master.
//
// AUTHORITY: pending_measurement. NOT fabrication authority until reviewed
// against a measured soprano prototype (see README "V5 Authority Boundary"
// and validation.csv VAL-BB-050). This is a codeCAD envelope master, not a
// reviewed/released CAD/DXF artifact.
//
// SOURCE OF TRUTH (do not hand-edit numbers below without updating these):
//   - build/packet/family-spec.csv        (root, bore_id_in, wall_thickness_in,
//                                           body_od_in, bell_od_in,
//                                           body_length_final_in)
//   - build/data/tone-hole-schedule.csv   (x_from_bell_in, hole_dia_in per
//                                           variant, holes K01,H01-H05,K02,H06,H07)
//   - build/cad/solidworks-design-table.csv mirrors the same two tables in a
//     flat CLM_* column layout for SolidWorks; values here match it.
// All dimensions are inches, matching the design table's native units.
//
// SCOPE: this master models the cylindrical BORE ENVELOPE and the TONE-HOLE
// POSITION SCHEDULE only. Per the V5 woodwind addendum, the following are
// explicitly OUT OF SCOPE and are NOT modeled here — they are tuning-sensitive
// regions that must be hand-refined against a measured prototype, not faked
// with placeholder geometry:
//   - mouthpiece geometry (facing, table, rails, tip opening)
//   - reed geometry / reed-and-mouthpiece assembly
//   - reed seat / mouthpiece tenon socket cut into the body
//   - tone-hole undercutting or chimney/collar tuning profile
//   - keywork (K01/K02 lever, pad, cup, pivot, post, spring — see
//     build/hardware/keywork-parts.csv, out of scope for this envelope)
// Tone holes are modeled as simple through-bores at the schedule's
// x_from_bell / diameter values, on a single row along -Y (the schedule has
// no per-hole rotation/angle column, so no angular placement is invented).
//
// Family plan (README): build order is soprano first (no levers, commercial
// reed/mouthpiece), then alto/tenor/bass after soprano correction data.

$fn = 96;

// ---- Per-variant body dimensions (build/packet/family-spec.csv) ----
// [id, bore_id_in, wall_thickness_in, body_od_in, bell_od_in, body_length_final_in, blank_length_in]
variant_body = [
  ["CLM-SOP-C4", 0.500, 0.188, 0.875, 1.65, 12.672, 14.172],
  ["CLM-ALT-G3", 0.625, 0.219, 1.063, 1.95, 16.939, 18.439],
  ["CLM-TEN-C3", 0.750, 0.250, 1.25,  2.35, 25.483, 26.983],
  ["CLM-BAS-F2", 0.875, 0.313, 1.5,   2.9,  38.320, 39.820],
];

// ---- Tone-hole schedule (build/data/tone-hole-schedule.csv) ----
// [x_from_bell_in, hole_dia_in, label] per variant, in K01..H07 schedule order.
tone_holes_sop = [
  [0.622, 0.160, "K01"], [1.314, 0.180, "H01"], [2.576, 0.190, "H02"],
  [3.147, 0.170, "H03"], [4.211, 0.190, "H04"], [5.157, 0.200, "H05"],
  [5.574, 0.150, "K02"], [5.988, 0.170, "H06"], [6.370, 0.160, "H07"],
];
tone_holes_alt = [
  [0.840, 0.200, "K01"], [1.763, 0.225, "H01"], [3.447, 0.238, "H02"],
  [4.209, 0.213, "H03"], [5.630, 0.238, "H04"], [6.892, 0.250, "H05"],
  [7.450, 0.188, "K02"], [8.002, 0.213, "H06"], [8.512, 0.200, "H07"],
];
tone_holes_ten = [
  [1.297, 0.240, "K01"], [2.678, 0.270, "H01"], [5.200, 0.285, "H02"],
  [6.345, 0.255, "H03"], [8.470, 0.285, "H04"], [10.361, 0.300, "H05"],
  [11.203, 0.225, "K02"], [12.028, 0.255, "H06"], [12.793, 0.240, "H07"],
];
tone_holes_bas = [
  [1.995, 0.280, "K01"], [4.061, 0.315, "H01"], [7.838, 0.333, "H02"],
  [9.557, 0.298, "H03"], [12.739, 0.333, "H04"], [15.570, 0.350, "H05"],
  [16.839, 0.263, "K02"], [18.071, 0.298, "H06"], [19.220, 0.280, "H07"],
];

function variant_index(id) =
  id == "CLM-SOP-C4" ? 0 :
  id == "CLM-ALT-G3" ? 1 :
  id == "CLM-TEN-C3" ? 2 :
  id == "CLM-BAS-F2" ? 3 : -1;

function tone_holes_for(id) =
  id == "CLM-SOP-C4" ? tone_holes_sop :
  id == "CLM-ALT-G3" ? tone_holes_alt :
  id == "CLM-TEN-C3" ? tone_holes_ten :
  id == "CLM-BAS-F2" ? tone_holes_bas : [];

// Cylindrical bore envelope: straight body with a bell flare at the foot end.
// The head (mouthpiece) end is left as a bare flat face — no tenon socket or
// mouthpiece geometry is modeled (out of scope, see header).
module chalumeau_bore_envelope(body_len, bore_id, body_od, bell_od, bell_flare_len = 1.6) {
  difference() {
    union() {
      cylinder(h = body_len, d = body_od);
      // bell flare at the foot (x=0 end, matches x_from_bell datum)
      translate([0, 0, -bell_flare_len])
        cylinder(h = bell_flare_len, d1 = bell_od, d2 = body_od);
    }
    translate([0, 0, -bell_flare_len - 1])
      cylinder(h = body_len + bell_flare_len + 2, d = bore_id);
  }
}

// Single tone hole, positioned by x_from_bell along the bore axis, drilled
// radially through the wall on the -Y face (schedule has no angle column).
module tone_hole(x_from_bell, dia, body_od) {
  translate([0, -body_od / 2, x_from_bell])
    rotate([90, 0, 0])
      cylinder(h = body_od, d = dia, center = true);
}

// Full variant: bore envelope with its tone-hole schedule subtracted.
module chalumeau_variant(id) {
  vi = variant_index(id);
  assert(vi >= 0, str("unknown variant id: ", id));
  b = variant_body[vi];
  bore_id  = b[1];
  body_od  = b[3];
  bell_od  = b[4];
  body_len = b[5];
  holes    = tone_holes_for(id);

  difference() {
    chalumeau_bore_envelope(body_len, bore_id, body_od, bell_od);
    for (h = holes) {
      tone_hole(h[0], h[1], body_od);
    }
  }
}

// ---- Top-level assembly ----
// Render one variant by default (soprano, the README's first-build target).
// Set SHOW_FAMILY = true to lay out all four variants side by side for
// review; each is still pending_measurement, not a fabrication release.
SELECTED_VARIANT = "CLM-SOP-C4";
SHOW_FAMILY = false;

if (SHOW_FAMILY) {
  gap = 3;
  for (i = [0 : len(variant_body) - 1]) {
    id = variant_body[i][0];
    x_offset = i * (variant_body[3][4] + gap); // space by largest bell OD (bass) + gap
    translate([x_offset, 0, 0])
      chalumeau_variant(id);
  }
} else {
  chalumeau_variant(SELECTED_VARIANT);
}

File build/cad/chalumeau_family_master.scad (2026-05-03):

// Chalumeau family OpenSCAD starter.
// Build-critical dimensions should be driven from SolidWorks/CSV before machining.

$fn = 96;

module chalumeau_body(body_len=12.672, bore_id=0.5, body_od=0.875, bell_od=1.65) {
  difference() {
    union() {
      cylinder(h=body_len, d=body_od);
      translate([0,0,-1.6]) cylinder(h=1.6, d1=bell_od, d2=body_od);
      translate([0,0,body_len]) cylinder(h=1.2, d=body_od*1.12);
    }
    translate([0,0,-2]) cylinder(h=body_len+4, d=bore_id);
  }
}

module tone_hole(x_from_bell, dia, body_od=0.875) {
  translate([0, -body_od/2, x_from_bell])
    rotate([90,0,0])
      cylinder(h=body_od, d=dia, center=true);
}

module soprano_c4_preview() {
  difference() {
    chalumeau_body();
    tone_hole(0.625, 0.160);
    tone_hole(1.335, 0.180);
    tone_hole(2.474, 0.190);
    tone_hole(3.004, 0.170);
    tone_hole(3.942, 0.190);
    tone_hole(4.787, 0.200);
    tone_hole(5.171, 0.150);
    tone_hole(5.544, 0.170);
    tone_hole(6.201, 0.160);
  }
}

soprano_c4_preview();

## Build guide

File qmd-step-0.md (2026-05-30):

# QMD Step 0 Record

Date: 2026-05-30.

Commands run after syncing `main` and before edits:

```sh
qmd search "chalumeau" -c instrument-builds
timeout 25 qmd query "chalumeau V5 packet"
```

Usable keyword hits:

- `instrument-builds/docs/plans/2026-05-17-r27-merge-and-winds/elsa.md`,
  noting `tonykoop/chalumeau` PR #3, "Add chalumeau bare-bones starter packet".
- `instrument-builds/.../headstock-driven-deep-bore-drilling.md`, which names
  prototype chalumeau or reed-pipe bores as a use case for straight cylindrical
  bore drilling.

Semantic query result:

- `qmd query "chalumeau V5 packet"` crashed inside Bun/node-llama after the
  timeout, ending with `timeout: the monitored command dumped core`.

Existing repo evidence used for this migration:

- `README.md`
- `design.md`
- `build/packet/design.md`
- `build/packet/drawing-brief.md`
- `build/packet/visual-bom-brief.md`
- `docs/image-attributions.md`

No QMD result supplied measured reed data, measured bore/tuning corrections,
reviewed CAD/DXF authority, or prototype validation evidence.

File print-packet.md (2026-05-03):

# Chalumeau Family Capstone Print Packet

Generated: 2026-05-03
Packet folder: `/mnt/c/Users/Tony/Documents/GitHub/chalumeau`

## File Map

| File | Purpose |
| --- | --- |
| `design.md` | Project intent, catalog metadata, assumptions, and validation plan. |
| `bom.csv` | Starter bill of materials with part categories, quantities, drawing refs, and notes. |
| `sourcing.csv` | Supplier/search tracker with specs, price/date fields, lead time, substitutes, and risks. |
| `cut-list.csv` | Rough/final stock sizes, material, grain/orientation, operations, yield, and offcuts. |
| `drawing-brief.md` | Manufacturing drawing and technical product sketch brief. |
| `assembly-manual.md` | Shop-facing sequence, tools, fixtures, safety, tuning, finishing, and maintenance notes. |
| `validation.csv` | Target/measured values, tolerance, environment, result, and tuning/build action log. |
| `supplier-rfq.md` | Supplier email/request-for-quote starter. |
| `visual-bom-brief.md` | Art direction for an image-forward visual BOM. |
| `wolfram-starter.wl` | Wolfram starter for physics, optimization, visualization, and validation. |
| `README.md` | Project artifact. |
| `SKILLS.md` | Project artifact. |
| `family-spec.csv` | Project artifact. |
| `image-attributions.md` | Project artifact. |

## design.md

Project intent, catalog metadata, assumptions, and validation plan.

# CLM-001 - Chalumeau Family

Generated: 2026-05-03

## Intent

Design a family of chalumeaux that can be built in Tony's shop using
lathe/CNC workflows, commercial reeds for early isolation tests, and
optional handmade metal keywork. The family should cover a useful range
without pretending the first-pass physics is final: all tone-hole
coordinates are starting points that must be validated with a real reed,
mouthpiece, bore, and player pressure.

## Source Artifacts

- Repo: `https://github.com/tonykoop/chalumeau`
- Attributed inspiration/reference photos: `images/chalumeau1.jpg` and
  `images/chalumeau5.jpg`, from Petr Skalicky / Dudy.eu:
  `https://www.dudy.eu/chalumeau.php`
- Additional local inspiration image: `images/7173-372-1_1920x1080.avif`
- Workbook inspected: `C:/Users/Tony/Documents/Claude/Projects/Career/flutes-staging/Musical Instruments.xlsx`
- Relevant workbook source sheet: `Great Highland Bagpipe`, especially the
  contrast between conical double-reed chanter rows and cylindrical
  single-reed drone rows.
- Done-bar reference style: `tongue-drum` repo packet and skill v3
  packet requirements.

## Governing Model

The chalumeau is modeled as a cylindrical single-reed pipe that behaves
like a stopped pipe in its low register.

```text
f = c / (4 * L_eff)
L_eff = c / (4 * f)
c = 13552 in/s at about 68 F
body_length = L_eff - bell_end_correction - reed_end_correction
bell_end_correction = 0.61 * bore_radius
reed_end_correction = 0.25 * bore_id   # first-pass assumption
tone_hole_x_from_bell = body_length - (c/(4*f_note) - reed_corr - 0.30*hole_dia)
cents_error = 1200 * log2(measured_hz / target_hz)
```

The model deliberately does not use Tony's NAF K2 corrections. Those
corrections are for open-open Native American style flutes in a specific
bore range. The chalumeau reed, stopped-pipe boundary condition,
mouthpiece volume, bore diameter, and tone-hole chimneys need their own
empirical correction after prototype measurement.

## Family Spec

| ID | Variant | Root | Bore ID | Final body L | Blank L | Sections |
| --- | --- | --- | --- | --- | --- | --- |
| CLM-SOP-C4 | Soprano C | C4 | 0.5 | 12.672 | 14.172 | 1 body + mouthpiece + bell |
| CLM-ALT-G3 | Alto G | G3 | 0.625 | 16.939 | 18.439 | 1 body + mouthpiece + bell |
| CLM-TEN-C3 | Tenor C | C3 | 0.75 | 25.483 | 26.983 | 2 body joints + mouthpiece + bell |
| CLM-BAS-F2 | Bass F | F2 | 0.875 | 38.32 | 39.82 | 3 body joints + mouthpiece + bell |

## Tone-Hole Strategy

- The keyless core uses seven front holes for a diatonic octave:
  offsets +2, +4, +5, +7, +9, +11, +12 semitones from the all-closed
  root.
- `K01` is an optional normally closed semitone key near the bell. It
  gives the first chromatic note above the root without forcing an
  awkward low finger stretch.
- `K02` is an optional upper chromatic side key. It gives a practical
  chromatic note between scale degrees 6 and 7 and doubles as a keywork
  fabrication exercise.
- A clarinet-style register vent is listed only as an experimental
  future feature. The first chalumeau should be judged by the low
  register before chasing overblown twelfths.

## Hardware Alignment

The hardware is intentionally small-shop manufacturable:

| Hardware | Role | First-build method | Upgrade path |
| --- | --- | --- | --- |
| K01 lever | opens low semitone tone hole | brass strip lever, pivot post pair, leather/cork pad | nickel-silver lever with soldered pad cup |
| K02 lever | opens upper chromatic tone hole | side lever with flat spring return | clarinet-style post/rod key with regulation cork |
| Optional register vent | tests clarinet evolution | leave undrilled until the body speaks well | small lined vent tube near mouthpiece |
| Raised tone-hole collars | ergonomic/aesthetic reference to photos | turn integral collars or add rings | separate stabilized-wood collars |

## SolidWorks Parameter Convention

Use `CLM_` as the project prefix, keep units in the variable name, and
use stable hole IDs that match the CSV and drawings:

- `CLM_Bore_ID_in`, `CLM_Body_L_Final_in`, `CLM_Bell_OD_in`
- `CLM_H01_X_Bell_in`, `CLM_H01_Dia_in`
- `CLM_K01_X_Bell_in`, `CLM_K01_Dia_in`
- `CLM_Key_Pivot_Rod_Dia_in`, `CLM_Pad_Overhang_in`

The SolidWorks design table is `cad/solidworks-design-table.csv`. The
equation snippets are in `cad/solidworks-equations.txt`.

## Assumptions And Risks

| Risk | Why it matters | Mitigation |
| --- | --- | --- |
| Reed/mouthpiece compliance shifts pitch | the reed is not a hard closed end | test with one commercial reed/mouthpiece before final hole tuning |
| Tone holes are first-pass estimates | small holes do not act as perfect open ends | drill undersized, tune larger, log every change |
| Bass holes exceed finger comfort | low instruments become large quickly | use key pads for lower/bigger holes |
| Handmade key pads leak | leaks ruin tuning and response | leak-light/suction test before pitch tuning |
| Dense oily woods complicate machining | cocobolo/ipe dust and finish issues | prototype in cherry/maple first |

## Validation Plan

1. Calibrate tuner/microphone at A4 = 440 Hz.
2. Build `CLM-SOP-C4` with no levers and a commercial reed/mouthpiece.
3. Tune the all-closed root by trimming the bell/foot only after reed
   response is stable.
4. Open holes from the bell upward, enlarging in small increments and
   logging measured frequency and cents error.
5. Add K01/K02 to either the same body or a second soprano body. Validate
   sealing before measuring pitch.
6. Update the empirical correction column in the design workbook before
   scaling to alto, tenor, or bass.

## Next Actions

- Confirm the actual reed and mouthpiece family for the soprano prototype.
- Decide whether the first body gets raised collars like the inspiration
  image or plain chamfered holes for faster tuning.
- Model `CLM-SOP-C4` in SolidWorks using the provided global variables.
- After first measurements, add a `prototype_correction_pct` column to
  `data/tone-hole-schedule.csv`.

## bom.csv

Starter bill of materials with part categories, quantities, drawing refs, and notes.

| item_no | subsystem | part_name | qty | material_spec | dimensions_spec | make_buy | estimated_cost | drawing_ref | notes |
| --- | --- | --- | --- | --- | --- | --- | --- | --- | --- |
| 1 | Body | Turned chalumeau body blanks | 4 | Cherry or hard maple for first pass; ipe/cocobolo/boxwood for keeper builds | see family-spec.csv blank_length_in and turning_blank_in | make | 80 | drawings/chalumeau-family-sheet.svg | Use lower-cost domestic hardwood for bore and keywork tests before dense/oily woods. |
| 2 | Bore | Long drill and reamer set | 1 | Aircraft-length brad point/twist drills plus adjustable/shell reamers | 0.500, 0.625, 0.750, 0.875 in bore targets | buy | 120 | cnc/cnc-lathe-plan.md | Exact tooling depends on whether bores are drilled solid or routed as split blanks. |
| 3 | Mouthpiece | Single-reed mouthpieces | 4 | Purchased clarinet/sax mouthpiece adapted by size, or shop-made Delrin mouthpiece | socket IDs in family-spec.csv; reed table in design.md | buy first, make later | 160 | drawing-brief.md | Use bought mouthpieces/reeds to isolate body acoustics before making reeds. |
| 4 | Tone holes | Raised tone-hole collars or drilled holes | 36 | Integral turned collars for visual style; chamfered holes for first prototype | see data/tone-hole-schedule.csv | make | 20 | drawings/chalumeau-soprano-c4-dimensioned.svg | Collars are visual and ergonomic; pitch comes from hole center, diameter, and chimney. |
| 5 | Keywork | Two-key chalumeau lever set | 4 | 0.040-0.062 in brass/nickel silver sheet, 1/16 in pivot rod, phosphor bronze spring | K01 and K02 per variant; see hardware/keywork-parts.csv | make | 60 | drawings/keywork-lever-detail.svg | The first soprano can be built keyless, then retrofitted with keys. |
| 6 | Pads | Leather/cork/felt pad stack | 12 | Clarinet-style skin pads or cork backed with thin leather | pad OD = tone hole OD + 0.080 to 0.125 in | buy or make | 35 | hardware/lever-fabrication-guide.md | Use leak light or suction test before tuning. |
| 7 | Finish | Oil/shellac finish and bore oil | 1 | Dewaxed shellac outside; bore oil compatible with chosen wood | finish schedule in assembly-manual.md | buy | 30 | assembly-manual.md | Avoid thick finish buildup inside tone holes or under pads. |

## sourcing.csv

Supplier/search tracker with specs, price/date fields, lead time, substitutes, and risks.

| component | required_spec | search_terms | supplier_candidates | date_checked | unit_price | lead_time | substitute_rule | risk_notes |
| --- | --- | --- | --- | --- | --- | --- | --- | --- |
| Domestic hardwood prototype blanks | Straight-grain cherry, hard maple, or walnut; 1.5-2.25 in square; length per family-spec.csv | turning blank cherry hard maple 2x2x18 2x2x30 | local hardwood dealer, Bell Forest, Cook Woods, Woodcraft | not live-checked | research before purchase | research before purchase | Any stable fine-grained hardwood is acceptable for first acoustic prototypes. | Soft woods dent around tone holes and key posts; use for process tests only. |
| Dense keeper-build blanks | Ipe, cocobolo, boxwood, rosewood, grenadilla substitute; dry and crack-free | ipe turning blank cocobolo clarinet blank boxwood woodwind blank | Gilmer Wood, Cook Woods, Bell Forest, specialty woodwind blank suppliers | not live-checked | research before purchase | research before purchase | Delrin/acetal is acceptable for dimensional-stability testing. | Allergenic/oily woods need dust control, wiping before glue, and finish tests. |
| Single reeds and mouthpieces | Soprano/alto use clarinet-like reeds; tenor/bass may use sax/low clarinet reeds or custom mouthpiece | clarinet mouthpiece blank baroque clarinet reed tenor chalumeau mouthpiece | woodwind suppliers, early-music makers, 3D print/Delrin shop-made option | not live-checked | research before purchase | research before purchase | Use commercial reed first to decouple reed-making from bore tuning. | Reed strength and mouthpiece volume can shift pitch and response significantly. |
| Brass/nickel-silver key stock | 0.040-0.062 in sheet, 1/16 in rod, 0-80 or M1.6 screws, post stock | nickel silver sheet woodwind key rod phosphor bronze spring wire | McMaster-Carr, K&S metals, MusicMedic, instrument repair suppliers | not live-checked | research before purchase | research before purchase | Brass is easier to prototype; nickel silver wears better and solders cleanly. | Tiny screws strip easily; buy extras and make drill guides. |
| Pads, cork, felt, leather | Clarinet/sax pads or leather-over-cork pads sized to K01/K02 tone holes | clarinet pads sheet cork felt key bumper leather pad cup | MusicMedic, Ferree's Tools, instrument repair suppliers | not live-checked | research before purchase | research before purchase | Cork plus thin leather is acceptable for first handmade keys. | Pad seating matters more than pad material for early prototypes. |

## cut-list.csv

Rough/final stock sizes, material, grain/orientation, operations, yield, and offcuts.

| part_id | variant | material | qty | rough_dimensions_in | final_dimensions_in | operation | grain_orientation | yield_notes |
| --- | --- | --- | --- | --- | --- | --- | --- | --- |
| CLM-SOP-C4-BODY | Soprano C | prototype hardwood | 1 | 1.25 x 1.25 x 14.172 | OD 0.875; bore 0.5; body length 12.672 | lathe turn, drill/ream bore, drill tone holes, final tune | long grain parallel to bore | leave 1.5 in length allowance and 0.1875 in OD cleanup allowance |
| CLM-SOP-C4-BELL | Soprano C | contrasting hardwood or same blank offcut | 1 | 2.025 x 2.025 x 3.000 | bell OD 1.65; socket fits bore/body OD by CAD | lathe turn bell flare and socket | long grain parallel to bore | use a separate bell to simplify tuning and repair |
| CLM-ALT-G3-BODY | Alto G | prototype hardwood | 1 | 1.438 x 1.438 x 18.439 | OD 1.063; bore 0.625; body length 16.939 | lathe turn, drill/ream bore, drill tone holes, final tune | long grain parallel to bore | leave 1.5 in length allowance and 0.1875 in OD cleanup allowance |
| CLM-ALT-G3-BELL | Alto G | contrasting hardwood or same blank offcut | 1 | 2.325 x 2.325 x 3.000 | bell OD 1.95; socket fits bore/body OD by CAD | lathe turn bell flare and socket | long grain parallel to bore | use a separate bell to simplify tuning and repair |
| CLM-TEN-C3-BODY | Tenor C | prototype hardwood | 1 | 1.625 x 1.625 x 26.983 | OD 1.25; bore 0.75; body length 25.483 | lathe turn, drill/ream bore, drill tone holes, final tune | long grain parallel to bore | leave 1.5 in length allowance and 0.1875 in OD cleanup allowance |
| CLM-TEN-C3-BELL | Tenor C | contrasting hardwood or same blank offcut | 1 | 2.725 x 2.725 x 3.000 | bell OD 2.35; socket fits bore/body OD by CAD | lathe turn bell flare and socket | long grain parallel to bore | use a separate bell to simplify tuning and repair |
| CLM-BAS-F2-BODY | Bass F | prototype hardwood | 1 | 1.875 x 1.875 x 39.82 | OD 1.5; bore 0.875; body length 38.32 | lathe turn, drill/ream bore, drill tone holes, final tune | long grain parallel to bore | leave 1.5 in length allowance and 0.1875 in OD cleanup allowance |
| CLM-BAS-F2-BELL | Bass F | contrasting hardwood or same blank offcut | 1 | 3.275 x 3.275 x 3.000 | bell OD 2.9; socket fits bore/body OD by CAD | lathe turn bell flare and socket | long grain parallel to bore | use a separate bell to simplify tuning and repair |

## drawing-brief.md

Manufacturing drawing and technical product sketch brief.

# Chalumeau Drawing Brief

Instrument: Chalumeau family
Revision/date: REV-A
Units: inches unless noted
Source workbook/CAD/catalog ID: CLM-001 / SolidWorks design table

## Required Views

- Family comparison side view with bore axis and body lengths.
- Soprano C dimensioned side view with all H/K hole coordinates.
- Cross-section through bore, tone-hole chimney, and raised collar.
- Keywork detail for K01/K02: closed/open positions, pad, cup, pivot,
  posts, spring, touchpiece.
- Exploded view: mouthpiece/reed, body, bell, K01, K02, pads, posts.
- Ergonomic view: hand reach for keyless soprano and keyed bass notes.

## Critical Dimensions

| Feature | Dimension source | Tolerance |
| --- | --- | --- |
| Bore ID | `family-spec.csv` | +/- 0.003 in after ream/lap |
| Body length | `family-spec.csv` | leave trim allowance; final by tuning |
| Hole X from bell | `data/tone-hole-schedule.csv` | +/- 0.020 in first prototype |
| Hole diameter | `data/tone-hole-schedule.csv` | start undersize; final by tuning |
| Pad seat flatness | `hardware/keywork-parts.csv` | no visible leak |
| Pivot alignment | keywork drawing | lever moves freely without side shake |

## Drawing Outputs In This Packet

- `drawings/chalumeau-family-sheet.svg`
- `drawings/chalumeau-soprano-c4-dimensioned.svg`
- `drawings/keywork-lever-detail.svg`

## Notes For SolidWorks

Drive dimensions from global variables. Do not dimension hole centers
manually in separate sketches unless the dimension names match the CSV.

## assembly-manual.md

Shop-facing sequence, tools, fixtures, safety, tuning, finishing, and maintenance notes.

# Chalumeau Assembly Manual

## Build Order

Build the soprano C keyless version first. Do not add keywork until the
bore, reed, and seven front holes speak reliably.

## Phase 0 - Design Freeze

1. Pick the exact reed and mouthpiece.
2. Print `data/tone-hole-schedule.csv` and mark which holes will be
   drilled in the first pass.
3. Decide whether the prototype uses raised collars or plain chamfered
   holes. Plain holes tune faster; collars match the inspiration photo.
4. Confirm the blank dimensions from `cut-list.csv`.

## Phase 1 - Body Blank And Bore

1. Mill/turn the blank oversize and mark the bore centerline.
2. Drill the bore from the reed-seat end with the longest stable drill
   setup available.
3. Ream or lap to final bore diameter. Measure at both ends.
4. Turn the exterior body profile, leaving extra length at the bell end.
5. Cut the mouthpiece socket/tenon but keep the reed setup removable.

## Phase 2 - Root Tuning

1. Assemble reed, mouthpiece, and body with all holes undrilled.
2. Measure the all-closed pitch.
3. Trim the bell/foot in small steps only after the reed is stable.
4. Record every trim amount in `validation.csv`.

## Phase 3 - Tone Holes

1. Lay out hole centers from `data/tone-hole-schedule.csv`, measuring
   from `DATUM_BELL_FACE`.
2. Center punch lightly. A wandering bit will change tuning.
3. Drill each hole 15-25 percent undersize.
4. Open holes from low to high. After each enlargement, play the target
   note and log measured frequency.
5. Chamfer only after pitch is close; chamfering can sharpen the note.

## Phase 4 - Optional K01/K02 Keywork

1. Drill keyed tone holes undersize.
2. Fabricate levers using `hardware/lever-fabrication-guide.md`.
3. Install posts and pivot rods.
4. Seat pads and leak-test before tuning.
5. Tune keyed notes after the pad seal is stable.

## Phase 5 - Finish

1. Sand exterior through 320 or finer.
2. Seal the bore lightly; avoid thick buildup.
3. Apply shellac/oil finish outside.
4. Keep finish out of tone holes and under pads.
5. Re-test all notes after finish cures.

## Maintenance Notes

- Swab the bore after playing.
- Check pad seating after humidity swings.
- Keep a build log for each reed/mouthpiece combination; reed strength
  can make the same body read sharp or flat.

## validation.csv

Target/measured values, tolerance, environment, result, and tuning/build action log.

| test_id | variant | target | target_value | measured_value | tolerance | environment | result | action |
| --- | --- | --- | --- | --- | --- | --- | --- | --- |
| VAL-001 | all | A4 reference | 440.00 Hz |  | tuner reads 440 within calibration | record temp F, humidity percent |  | Calibrate tuner/mic before instrument data. |
| VAL-010 | Soprano C | all holes closed | C4, 261.63 Hz |  | +/- 15 cents before final tuning; +/- 8 cents after | 68-72 F preferred |  | Trim bell end shorter to sharpen; add temporary tape/extension if sharp. |
| VAL-020 | all | tone-hole sweep | each row in data/tone-hole-schedule.csv |  | +/- 12 cents after tuning | same reed, same mouthpiece, same blowing pressure |  | Open hole diameter to sharpen; use wax/tape collar to flatten during tests. |
| VAL-030 | keyed builds | pad leak test | no visible leak under leak light; suction holds 10 s |  | zero audible hiss at normal blowing pressure | before final tone-hole tuning |  | Reseat pad, regulate cork, or lap tone-hole rim. |
| VAL-040 | experimental register key | overblown twelfth check | note + 19 semitones if vent is clarinet-like |  | document response only; not a first-build pass/fail | same reed and embouchure as low-register test |  | Move/resize vent only after the core chalumeau speaks well. |

## supplier-rfq.md

Supplier email/request-for-quote starter.

# Supplier RFQ - Chalumeau Materials And Keywork

Hello,

I am sourcing materials for a small family of handmade single-reed
chalumeaux. Please quote the items below, including unit price, volume
price if applicable, lead time, shipping estimate, and any recommended
substitutes.

## Wood Or Plastic Blanks

- Straight-grain turning blanks suitable for woodwind bodies.
- Prototype species: cherry, hard maple, walnut, or Delrin/acetal.
- Keeper species: ipe, boxwood, cocobolo, rosewood, or grenadilla
  substitute.
- Sizes range from about 1.25 x 1.25 x 15 in to 2.25 x 2.25 x 41 in.
  Exact dimensions are in `cut-list.csv`.

## Keywork Materials

- Brass or nickel-silver sheet, 0.040-0.062 in thick.
- 1/16 in rod or equivalent pivot stock.
- Small screws, post stock, and phosphor bronze spring wire.
- Clarinet/sax pads or pad leather/cork materials.

## Requirements

- Material must be stable, dry, and suitable for fine drilling/turning.
- Please identify any allergy/dust or finish compatibility concerns.
- Substitutions are acceptable if dimensional stability and machinability
  are comparable.

Thank you.

## visual-bom-brief.md

Art direction for an image-forward visual BOM.

# Visual BOM Brief

## Layout

Use the Ashiko visual BOM pattern: hero image at the top, spreadsheet
rows below, and one part image/render per row. Use the actual local
chalumeau photos for the hero/inspiration image until Tony has shop
photos of the prototypes.

## Real Images Available

- `images/chalumeau1.jpg`: full instrument inspiration, attributed to
  Petr Skalicky / Dudy.eu, `https://www.dudy.eu/chalumeau.php`.
- `images/chalumeau5.jpg`: close-up of raised collars and wood finish,
  attributed to Petr Skalicky / Dudy.eu, `https://www.dudy.eu/chalumeau.php`.
- `images/7173-372-1_1920x1080.avif`: additional inspiration image,
  not universally supported by all renderers.

## Part Rows To Show

1. Turned body blank.
2. Mouthpiece/reed assembly.
3. Bell.
4. H01-H07 tone-hole row with raised collars.
5. K01 low semitone lever.
6. K02 side chromatic lever.
7. Pad/cork/felt stack.
8. Pivot posts, rods, springs, screws.
9. Finish and bore oil.

## Placeholder Policy

Generated or schematic part images are acceptable for planning, but mark
them as placeholders until replaced with supplier images or shop photos.
Build-critical dimensions must come from the CSV/workbook/SolidWorks,
not from pixels in the visual BOM.

## wolfram-starter.wl

Wolfram starter for physics, optimization, visualization, and validation.

```wolfram
(* Chalumeau family acoustic starter - generated 2026-05-03 *)

ClearAll["Global`*"];

speedOfSoundInPerSec = 13552.0;
midiFrequency[m_] := 440*2^((m - 69)/12);
centsError[measured_, target_] := 1200*Log2[measured/target];

bodyLength[rootMidi_, boreID_] := Module[
  {f = midiFrequency[rootMidi], acoustic, bellCorr, reedCorr},
  acoustic = speedOfSoundInPerSec/(4*f);
  bellCorr = 0.61*(boreID/2);
  reedCorr = 0.25*boreID;
  acoustic - bellCorr - reedCorr
];

holeXFromBell[rootMidi_, offset_, boreID_, holeRatio_] := Module[
  {f = midiFrequency[rootMidi + offset], holeDia, holeCorr, reedCorr, eff, body},
  holeDia = boreID*holeRatio;
  holeCorr = 0.30*holeDia;
  reedCorr = 0.25*boreID;
  eff = speedOfSoundInPerSec/(4*f);
  body = bodyLength[rootMidi, boreID];
  body - (eff - reedCorr - holeCorr)
];

variants = {
  <|"ID" -> "CLM-SOP-C4", "RootMIDI" -> 60, "BoreID" -> 0.500|>,
  <|"ID" -> "CLM-ALT-G3", "RootMIDI" -> 55, "BoreID" -> 0.625|>,
  <|"ID" -> "CLM-TEN-C3", "RootMIDI" -> 48, "BoreID" -> 0.750|>,
  <|"ID" -> "CLM-BAS-F2", "RootMIDI" -> 41, "BoreID" -> 0.875|>
};

holeOffsets = {1, 2, 4, 5, 7, 9, 10, 11, 12};
holeRatios = {0.32, 0.36, 0.38, 0.34, 0.38, 0.40, 0.30, 0.34, 0.32};

familyTable = Table[
  With[{v = variants[[i]]},
    <|
      "ID" -> v["ID"],
      "RootHz" -> midiFrequency[v["RootMIDI"]],
      "BodyLengthIn" -> bodyLength[v["RootMIDI"], v["BoreID"]],
      "HolePositionsFromBellIn" -> MapThread[
holeXFromBell[v["RootMIDI"], #1, v["BoreID"], #2]&,
{holeOffsets, holeRatios}
      ]
    |>
  ],
  {i, Length[variants]}
];

Dataset[familyTable]

Manipulate[
  Plot[
    speedOfSoundInPerSec/(4*(x + 0.61*(bore/2) + 0.25*bore)),
    {x, 4, 42},
    PlotRange -> {80, 700},
    AxesLabel -> {"Body length (in)", "Frequency (Hz)"},
    PlotLabel -> "Stopped cylindrical reed bore first-pass model"
  ],
  {{bore, 0.5, "Bore ID (in)"}, 0.35, 1.0}
]
```

## README.md

Project artifact.

# Chalumeau Family

> A build-ready design packet for a family of single-reed chalumeaux:
> keyless folk-pipe simplicity first, optional handmade two-key metalwork
> second, and a documented path toward clarinet-style register experiments.

Inspiration chalumeau with turned wood body, raised tone-hole collars, black mouthpiece, and flared bell
*Photo/reference instrument by Petr Skalicky / Dudy.eu, from
[dudy.eu/chalumeau.php](https://www.dudy.eu/chalumeau.php). Used here
as an attributed design reference, not as Tony's own build photo.*

## GitHub Repo Metadata

**Description:** Parametric build packet for a handmade chalumeau family,
including stopped-reed acoustics, tone-hole schedules, SolidWorks design
tables, and DIY keywork.

**Suggested topics:** `chalumeau`, `woodwind`, `single-reed`,
`clarinet-history`, `instrument-making`, `parametric-design`,
`solidworks`, `acoustic-modeling`, `cnc-lathe`, `woodworking`,
`music-technology`, `build-packet`

## What this is

This repository now contains a complete first-pass engineering packet for
designing and building a family of chalumeaux in soprano C, alto G, tenor
C, and bass F. The design is parametric: body length, bore, tone-hole
positions, and optional levers are driven from formulas rather than
hidden one-off dimensions.

The packet starts from attributed Dudy.eu chalumeau reference photos in
`images/`, Tony's `Musical Instruments.xlsx` workbook, and especially
the reed/bore lessons in the `Great Highland Bagpipe` sheet. The
acoustic model is not copied from Native American style flute K2
corrections. A chalumeau is a cylindrical, single-reed, effectively
stopped pipe, so it gets its own validation loop.

## Family plan

| ID | Variant | Root | Bore ID | Final body L | Blank L | Sections |
| --- | --- | --- | --- | --- | --- | --- |
| CLM-SOP-C4 | Soprano C | C4 | 0.5 | 12.672 | 14.172 | 1 body + mouthpiece + bell |
| CLM-ALT-G3 | Alto G | G3 | 0.625 | 16.939 | 18.439 | 1 body + mouthpiece + bell |
| CLM-TEN-C3 | Tenor C | C3 | 0.75 | 25.483 | 26.983 | 2 body joints + mouthpiece + bell |
| CLM-BAS-F2 | Bass F | F2 | 0.875 | 38.32 | 39.82 | 3 body joints + mouthpiece + bell |

The recommended build order is `CLM-SOP-C4` first, with no levers, using
a commercial reed/mouthpiece. Once that speaks cleanly, add the two
optional levers to the same body or a second soprano body. Then scale up
to alto, tenor, and bass.

## Why some have levers

Keyless chalumeaux are mechanically close to folk reed pipes: finger
holes cover the notes that are reachable by hand. A few levers appear
when a useful tone hole is too low, too high, too large, or too awkward
to cover directly. The historical two-key chalumeau/early clarinet
moment is exactly that transition: keys first helped extend and smooth
the low register, then the clarinet moved one key into a better register
vent position and gradually accumulated more keys for chromatic notes,
trills, low extensions, and better intonation.

## Packet map

- `chalumeau-family-design-table.xlsx`: Excel design workbook with blue
  inputs and formulas.
- `family-spec.csv`: one row per family member.
- `data/tone-hole-schedule.csv`: calculated tone-hole and keyed-hole
  positions.
- `design.md`: governing model, assumptions, keywork strategy, and risk
  register.
- `hardware/lever-fabrication-guide.md`: how to make the metal levers,
  pads, pivots, and springs yourself.
- `cad/solidworks-design-table.csv`: SolidWorks configuration table.
- `cad/solidworks-global-variables.md`: variable naming conventions and
  equation pattern.
- `drawings/`: SVG drawing sheets for the family, soprano C, and keywork.
- `assembly-manual.md`, `bom.csv`, `sourcing.csv`, `cut-list.csv`,
  `validation.csv`, `supplier-rfq.md`: shop-facing build packet files.
- `wolfram-starter.wl`: Wolfram starter for acoustic sweeps and tuning
  validation.
- `capstone-deck.pptx` and `print-packet.pdf`: presentation and printable
  versions of the packet.

## Status

| Area | Status |
| --- | --- |
| Acoustic model | first-order stopped cylindrical reed model complete |
| Parametric family table | complete, with formulas and SolidWorks export |
| Keywork concept | two-key handmade lever system specified |
| Manufacturing drawings | SVG first-pass sheets complete |
| Shop build method | complete for prototype workflow |
| Tuning validation | template ready; needs measured prototype data |
| SolidWorks | variable conventions and design table ready |

## License

Released under [CC-BY 4.0](LICENSE) for original written/design content
in this repository. The Dudy.eu reference photos are attributed source
images, not Tony-owned build photos; replace them with shop photos as
prototypes are built.

## SKILLS.md

Project artifact.

# Skills Demonstrated

## stopped-cylindrical-reed-bore

Models a single-reed cylindrical bore as a stopped pipe in the low
register, with explicit reed and bell end-correction assumptions.

## handmade-woodwind-keywork

Designs and fabricates simple early-woodwind levers using brass or
nickel silver, pivot rods, pads, posts, and springs.

## solidworks-parametric-family-table

Uses one design table to drive multiple instrument-family
configurations, with stable named dimensions that match CSV, drawings,
and validation logs.

## empirical-tone-hole-validation

Starts with physics-derived hole positions, then tunes the real
prototype by measured frequency and cents error rather than trusting the
first-pass model blindly.

## family-spec.csv

Project artifact.

| instrument_id | variant | root_note | root_midi | root_frequency_hz | bore_id_in | wall_thickness_in | body_od_in | bell_od_in | acoustic_length_in | body_length_final_in | blank_length_in | turning_blank_in | sections | build_priority | status |
| --- | --- | --- | --- | --- | --- | --- | --- | --- | --- | --- | --- | --- | --- | --- | --- |
| CLM-SOP-C4 | Soprano C | C4 | 60 | 261.63 | 0.5 | 0.188 | 0.875 | 1.65 | 12.95 | 12.672 | 14.172 | 1.25 x 1.25 x 14.172 | 1 body + mouthpiece + bell | Prototype 1 | first-order design; validate after reed and bore prototype |
| CLM-ALT-G3 | Alto G | G3 | 55 | 196.0 | 0.625 | 0.219 | 1.063 | 1.95 | 17.286 | 16.939 | 18.439 | 1.438 x 1.438 x 18.439 | 1 body + mouthpiece + bell | Prototype 2 | first-order design; validate after reed and bore prototype |
| CLM-TEN-C3 | Tenor C | C3 | 48 | 130.81 | 0.75 | 0.25 | 1.25 | 2.35 | 25.9 | 25.483 | 26.983 | 1.625 x 1.625 x 26.983 | 2 body joints + mouthpiece + bell | Prototype 3 | first-order design; validate after reed and bore prototype |
| CLM-BAS-F2 | Bass F | F2 | 41 | 87.31 | 0.875 | 0.313 | 1.5 | 2.9 | 38.806 | 38.32 | 39.82 | 1.875 x 1.875 x 39.82 | 3 body joints + mouthpiece + bell | Stretch prototype | first-order design; validate after reed and bore prototype |

## image-attributions.md

Project artifact.

# Image Attributions

## Dudy.eu Chalumeau Reference Photos

- `images/chalumeau1.jpg`
- `images/chalumeau5.jpg`

Attribution: Petr Skalicky / Dudy.eu, chalumeau reference page:
https://www.dudy.eu/chalumeau.php

Use in this repo: attributed visual reference for form, finish, raised
tone-hole collars, mouthpiece layout, and bell styling. These are not Tony's
own build photos.

## Additional Local Inspiration Image

- `images/7173-372-1_1920x1080.avif`

Attribution/source: TBD. Keep as local inspiration only until provenance is
confirmed or replace with shop-generated imagery.

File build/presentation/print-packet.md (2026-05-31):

# Chalumeau Family Capstone Print Packet

Generated: 2026-05-03
Packet folder: `/mnt/c/Users/Tony/Documents/GitHub/chalumeau`

## File Map

| File | Purpose |
| --- | --- |
| `../packet/design.md` | Project intent, catalog metadata, assumptions, and validation plan. |
| `../packet/bom.csv` | Starter bill of materials with part categories, quantities, drawing refs, and notes. |
| `../packet/sourcing.csv` | Supplier/search tracker with specs, price/date fields, lead time, substitutes, and risks. |
| `../packet/cut-list.csv` | Rough/final stock sizes, material, grain/orientation, operations, yield, and offcuts. |
| `../packet/drawing-brief.md` | Manufacturing drawing and technical product sketch brief. |
| `../packet/assembly-manual.md` | Shop-facing sequence, tools, fixtures, safety, tuning, finishing, and maintenance notes. |
| `../packet/validation.csv` | Target/measured values, tolerance, environment, result, and tuning/build action log. |
| `../packet/supplier-rfq.md` | Supplier email/request-for-quote starter. |
| `../packet/visual-bom-brief.md` | Art direction for an image-forward visual BOM. |
| `../packet/chalumeau-packet-starter.wl` | Wolfram starter for physics, optimization, visualization, and validation. |
| `README.md` | Project artifact. |
| `../../docs/SKILLS.md` | Project artifact. |
| `../packet/family-spec.csv` | Project artifact. |
| `../../docs/image-attributions.md` | Project artifact. |

## ../packet/design.md

Project intent, catalog metadata, assumptions, and validation plan.

# CLM-001 - Chalumeau Family

Generated: 2026-05-03

## Intent

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

## Source Artifacts

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

## Governing Model

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

```text
f = c / (4 * L_eff)
L_eff = c / (4 * f)
c = 13552 in/s at about 68 F
body_length = L_eff - bell_end_correction - reed_end_correction
bell_end_correction = 0.61 * bore_radius
reed_end_correction = 0.25 * bore_id   # first-pass assumption
tone_hole_x_from_bell = body_length - (c/(4*f_note) - reed_corr - 0.30*hole_dia)
cents_error = 1200 * log2(measured_hz / target_hz)
```

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

## Family Spec

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

## Tone-Hole Strategy

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

## Hardware Alignment

The hardware is intentionally small-shop manufacturable:

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

## SolidWorks Parameter Convention

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

- `CLM_Bore_ID_in`, `CLM_Body_L_Final_in`, `CLM_Bell_OD_in`
- `CLM_H01_X_Bell_in`, `CLM_H01_Dia_in`
- `CLM_K01_X_Bell_in`, `CLM_K01_Dia_in`
- `CLM_Key_Pivot_Rod_Dia_in`, `CLM_Pad_Overhang_in`

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

## Assumptions And Risks

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

## Validation Plan

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

## Next Actions

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

## ../packet/bom.csv

Starter bill of materials with part categories, quantities, drawing refs, and notes.

| item_no | subsystem | part_name | qty | material_spec | dimensions_spec | make_buy | estimated_cost | drawing_ref | notes |
| --- | --- | --- | --- | --- | --- | --- | --- | --- | --- |
| 1 | Body | Turned chalumeau body blanks | 4 | Cherry or hard maple for first pass; ipe/cocobolo/boxwood for keeper builds | see ../packet/family-spec.csv blank_length_in and turning_blank_in | make | 80 | ../drawings/chalumeau-family-sheet.svg | Use lower-cost domestic hardwood for bore and keywork tests before dense/oily woods. |
| 2 | Bore | Long drill and reamer set | 1 | Aircraft-length brad point/twist drills plus adjustable/shell reamers | 0.500, 0.625, 0.750, 0.875 in bore targets | buy | 120 | ../cnc/cnc-lathe-plan.md | Exact tooling depends on whether bores are drilled solid or routed as split blanks. |
| 3 | Mouthpiece | Single-reed mouthpieces | 4 | Purchased clarinet/sax mouthpiece adapted by size, or shop-made Delrin mouthpiece | socket IDs in ../packet/family-spec.csv; reed table in ../packet/design.md | buy first, make later | 160 | ../packet/drawing-brief.md | Use bought mouthpieces/reeds to isolate body acoustics before making reeds. |
| 4 | Tone holes | Raised tone-hole collars or drilled holes | 36 | Integral turned collars for visual style; chamfered holes for first prototype | see ../data/tone-hole-schedule.csv | make | 20 | ../drawings/chalumeau-soprano-c4-dimensioned.svg | Collars are visual and ergonomic; pitch comes from hole center, diameter, and chimney. |
| 5 | Keywork | Two-key chalumeau lever set | 4 | 0.040-0.062 in brass/nickel silver sheet, 1/16 in pivot rod, phosphor bronze spring | K01 and K02 per variant; see ../hardware/keywork-parts.csv | make | 60 | ../drawings/keywork-lever-detail.svg | The first soprano can be built keyless, then retrofitted with keys. |
| 6 | Pads | Leather/cork/felt pad stack | 12 | Clarinet-style skin pads or cork backed with thin leather | pad OD = tone hole OD + 0.080 to 0.125 in | buy or make | 35 | ../hardware/lever-fabrication-guide.md | Use leak light or suction test before tuning. |
| 7 | Finish | Oil/shellac finish and bore oil | 1 | Dewaxed shellac outside; bore oil compatible with chosen wood | finish schedule in ../packet/assembly-manual.md | buy | 30 | ../packet/assembly-manual.md | Avoid thick finish buildup inside tone holes or under pads. |

## ../packet/sourcing.csv

Supplier/search tracker with specs, price/date fields, lead time, substitutes, and risks.

| component | required_spec | search_terms | supplier_candidates | date_checked | unit_price | lead_time | substitute_rule | risk_notes |
| --- | --- | --- | --- | --- | --- | --- | --- | --- |
| Domestic hardwood prototype blanks | Straight-grain cherry, hard maple, or walnut; 1.5-2.25 in square; length per ../packet/family-spec.csv | turning blank cherry hard maple 2x2x18 2x2x30 | local hardwood dealer, Bell Forest, Cook Woods, Woodcraft | not live-checked | research before purchase | research before purchase | Any stable fine-grained hardwood is acceptable for first acoustic prototypes. | Soft woods dent around tone holes and key posts; use for process tests only. |
| Dense keeper-build blanks | Ipe, cocobolo, boxwood, rosewood, grenadilla substitute; dry and crack-free | ipe turning blank cocobolo clarinet blank boxwood woodwind blank | Gilmer Wood, Cook Woods, Bell Forest, specialty woodwind blank suppliers | not live-checked | research before purchase | research before purchase | Delrin/acetal is acceptable for dimensional-stability testing. | Allergenic/oily woods need dust control, wiping before glue, and finish tests. |
| Single reeds and mouthpieces | Soprano/alto use clarinet-like reeds; tenor/bass may use sax/low clarinet reeds or custom mouthpiece | clarinet mouthpiece blank baroque clarinet reed tenor chalumeau mouthpiece | woodwind suppliers, early-music makers, 3D print/Delrin shop-made option | not live-checked | research before purchase | research before purchase | Use commercial reed first to decouple reed-making from bore tuning. | Reed strength and mouthpiece volume can shift pitch and response significantly. |
| Brass/nickel-silver key stock | 0.040-0.062 in sheet, 1/16 in rod, 0-80 or M1.6 screws, post stock | nickel silver sheet woodwind key rod phosphor bronze spring wire | McMaster-Carr, K&S metals, MusicMedic, instrument repair suppliers | not live-checked | research before purchase | research before purchase | Brass is easier to prototype; nickel silver wears better and solders cleanly. | Tiny screws strip easily; buy extras and make drill guides. |
| Pads, cork, felt, leather | Clarinet/sax pads or leather-over-cork pads sized to K01/K02 tone holes | clarinet pads sheet cork felt key bumper leather pad cup | MusicMedic, Ferree's Tools, instrument repair suppliers | not live-checked | research before purchase | research before purchase | Cork plus thin leather is acceptable for first handmade keys. | Pad seating matters more than pad material for early prototypes. |

## ../packet/cut-list.csv

Rough/final stock sizes, material, grain/orientation, operations, yield, and offcuts.

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

## ../packet/drawing-brief.md

Manufacturing drawing and technical product sketch brief.

# Chalumeau Drawing Brief

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

## Required Views

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

## Critical Dimensions

| Feature | Dimension source | Tolerance |
| --- | --- | --- |
| Bore ID | `../packet/family-spec.csv` | +/- 0.003 in after ream/lap |
| Body length | `../packet/family-spec.csv` | leave trim allowance; final by tuning |
| Hole X from bell | `../data/tone-hole-schedule.csv` | +/- 0.020 in first prototype |
| Hole diameter | `../data/tone-hole-schedule.csv` | start undersize; final by tuning |
| Pad seat flatness | `../hardware/keywork-parts.csv` | no visible leak |
| Pivot alignment | keywork drawing | lever moves freely without side shake |

## Drawing Outputs In This Packet

- `../drawings/chalumeau-family-sheet.svg`
- `../drawings/chalumeau-soprano-c4-dimensioned.svg`
- `../drawings/keywork-lever-detail.svg`

## Notes For SolidWorks

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

## ../packet/assembly-manual.md

Shop-facing sequence, tools, fixtures, safety, tuning, finishing, and maintenance notes.

# Chalumeau Assembly Manual

## Build Order

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

## Phase 0 - Design Freeze

1. Pick the exact reed and mouthpiece.
2. Print `../data/tone-hole-schedule.csv` and mark which holes will be
   drilled in the first pass.
3. Decide whether the prototype uses raised collars or plain chamfered
   holes. Plain holes tune faster; collars match the inspiration photo.
4. Confirm the blank dimensions from `../packet/cut-list.csv`.

## Phase 1 - Body Blank And Bore

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

## Phase 2 - Root Tuning

1. Assemble reed, mouthpiece, and body with all holes undrilled.
2. Measure the all-closed pitch.
3. Trim the bell/foot in small steps only after the reed is stable.
4. Record every trim amount in `../packet/validation.csv`.

## Phase 3 - Tone Holes

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

## Phase 4 - Optional K01/K02 Keywork

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

## Phase 5 - Finish

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

## Maintenance Notes

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

## ../packet/validation.csv

Target/measured values, tolerance, environment, result, and tuning/build action log.

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

## ../packet/supplier-rfq.md

Supplier email/request-for-quote starter.

# Supplier RFQ - Chalumeau Materials And Keywork

Hello,

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

## Wood Or Plastic Blanks

- Straight-grain turning blanks suitable for woodwind bodies.
- Prototype species: cherry, hard maple, walnut, or Delrin/acetal.
- Keeper species: ipe, boxwood, cocobolo, rosewood, or grenadilla
  substitute.
- Sizes range from about 1.25 x 1.25 x 15 in to 2.25 x 2.25 x 41 in.
  Exact dimensions are in `../packet/cut-list.csv`.

## Keywork Materials

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

## Requirements

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

Thank you.

## ../packet/visual-bom-brief.md

Art direction for an image-forward visual BOM.

# Visual BOM Brief

## Layout

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

## Real Images Available

- `../../assets/images/chalumeau1.jpg`: full instrument inspiration, attributed to
  Petr Skalicky / Dudy.eu, `https://www.dudy.eu/chalumeau.php`.
- `../../assets/images/chalumeau5.jpg`: close-up of raised collars and wood finish,
  attributed to Petr Skalicky / Dudy.eu, `https://www.dudy.eu/chalumeau.php`.
- `../../assets/images/7173-372-1_1920x1080.avif`: additional inspiration image,
  not universally supported by all renderers.

## Part Rows To Show

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

## Placeholder Policy

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

## ../packet/chalumeau-packet-starter.wl

Wolfram starter for physics, optimization, visualization, and validation.

```wolfram
(* Chalumeau family acoustic starter - generated 2026-05-03 *)

ClearAll["Global`*"];

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

Dataset[familyTable]

Manipulate[
  Plot[
    speedOfSoundInPerSec/(4*(x + 0.61*(bore/2) + 0.25*bore)),
    {x, 4, 42},
    PlotRange -> {80, 700},
    AxesLabel -> {"Body length (in)", "Frequency (Hz)"},
    PlotLabel -> "Stopped cylindrical reed bore first-pass model"
  ],
  {{bore, 0.5, "Bore ID (in)"}, 0.35, 1.0}
]
```

## README.md

Project artifact.

# Chalumeau Family

> A prototype validation packet for a family of single-reed chalumeaux:
> keyless folk-pipe simplicity first, optional handmade two-key metalwork
> second, and a documented path toward clarinet-style register experiments.

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

## GitHub Repo Metadata

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

## What this is

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

## Family plan

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

## Why some have levers

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

## Packet map

- `chalumeau-family-design-table.xlsx`: Excel design workbook with blue
  inputs and formulas.
- `../packet/family-spec.csv`: one row per family member.
- `../data/tone-hole-schedule.csv`: calculated tone-hole and keyed-hole
  positions.
- `../packet/design.md`: governing model, assumptions, keywork strategy, and risk
  register.
- `../hardware/lever-fabrication-guide.md`: how to make the metal levers,
  pads, pivots, and springs yourself.
- `../cad/solidworks-design-table.csv`: SolidWorks configuration table.
- `../cad/solidworks-global-variables.md`: variable naming conventions and
  equation pattern.
- `../drawings/`: SVG drawing sheets for the family, soprano C, and keywork.
- `../packet/assembly-manual.md`, `../packet/bom.csv`, `../packet/sourcing.csv`, `../packet/cut-list.csv`,
  `../packet/validation.csv`, `../packet/supplier-rfq.md`: shop-facing build packet files.
- `../packet/chalumeau-packet-starter.wl`: Wolfram starter for acoustic sweeps and tuning
  validation.
- `capstone-deck.pptx` and `print-packet.pdf`: presentation and printable
  versions of the packet.

## Status

| Area | Status |
| --- | --- |
| Acoustic model | first-order stopped cylindrical reed model complete |
| Parametric family table | complete, with formulas and SolidWorks export |
| Keywork concept | two-key handmade lever system specified |
| Manufacturing drawings | SVG first-pass sheets complete |
| Shop build method | complete for prototype workflow |
| Reed/tuning validation | capture templates and validation loop ready; needs measured prototype data |
| SolidWorks | variable conventions and design table ready |

## License

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

## ../../docs/SKILLS.md

Project artifact.

# Skills Demonstrated

## stopped-cylindrical-reed-bore

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

## handmade-woodwind-keywork

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

## solidworks-parametric-family-table

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

## empirical-tone-hole-validation

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

## ../packet/family-spec.csv

Project artifact.

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

## ../../docs/image-attributions.md

Project artifact.

# Image Attributions

## Dudy.eu Chalumeau Reference Photos

- `../../assets/images/chalumeau1.jpg`
- `../../assets/images/chalumeau5.jpg`

Attribution: Petr Skalicky / Dudy.eu, chalumeau reference page:
https://www.dudy.eu/chalumeau.php

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

## Additional Local Inspiration Image

- `../../assets/images/7173-372-1_1920x1080.avif`

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

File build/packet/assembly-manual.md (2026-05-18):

# Chalumeau Assembly Manual

## Build Order

Build the soprano C keyless version first. Do not add keywork until the
bore, reed, and seven front holes speak reliably.

## Phase 0 - Design Freeze

1. Pick the exact reed and mouthpiece.
   Record it in `../data/reed-mouthpiece-capture-template.csv`.
2. Print `../data/tone-hole-schedule.csv` and mark which holes will be
   drilled in the first pass.
3. Decide whether the prototype uses raised collars or plain chamfered
   holes. Plain holes tune faster; collars match the inspiration photo.
4. Confirm the blank dimensions from `cut-list.csv`.

## Phase 1 - Body Blank And Bore

1. Mill/turn the blank oversize and mark the bore centerline.
2. Drill the bore from the reed-seat end with the longest stable drill
   setup available.
3. Ream or lap to final bore diameter. Measure at both ends.
   Record station measurements in `../data/bore-trim-capture-template.csv`.
4. Turn the exterior body profile, leaving extra length at the bell end.
5. Cut the mouthpiece socket/tenon but keep the reed setup removable.

## Phase 2 - Root Tuning

1. Assemble reed, mouthpiece, and body with all holes undrilled.
2. Measure the all-closed pitch.
3. Trim the bell/foot in small steps only after the reed is stable.
4. Record every trim amount in `../data/bore-trim-capture-template.csv`
   and carry the pass/fail result into `validation.csv`.

## Phase 3 - Tone Holes

1. Lay out hole centers from `../data/tone-hole-schedule.csv`, measuring
   from `DATUM_BELL_FACE`.
2. Center punch lightly. A wandering bit will change tuning.
3. Drill each hole 15-25 percent undersize.
4. Open holes from low to high. After each enlargement, play the target
   note and log measured frequency in `../data/tuning-capture-template.csv`.
5. Chamfer only after pitch is close; chamfering can sharpen the note.

## Phase 4 - Optional K01/K02 Keywork

1. Drill keyed tone holes undersize.
2. Fabricate levers using `../hardware/lever-fabrication-guide.md`.
3. Install posts and pivot rods.
4. Seat pads and leak-test before tuning.
5. Tune keyed notes after the pad seal is stable.

## Phase 5 - Finish

1. Sand exterior through 320 or finer.
2. Seal the bore lightly; avoid thick buildup.
3. Apply shellac/oil finish outside.
4. Keep finish out of tone holes and under pads.
5. Re-test all notes after finish cures.

## Maintenance Notes

- Swab the bore after playing.
- Check pad seating after humidity swings.
- Keep a build log for each reed/mouthpiece combination; reed strength
  can make the same body read sharp or flat.

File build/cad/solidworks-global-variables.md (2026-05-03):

# SolidWorks Global Variable Naming

## Naming Rules

- Prefix every chalumeau global variable with `CLM_`.
- Use stable hole IDs: `H01` through `H07` for finger holes, `K01` and
  `K02` for keyed holes.
- Include units in the name when the variable is dimensional:
  `_in`, `_deg`, `_Hz`, `_pct`.
- Use `X_Bell` for coordinates measured from the bell/foot datum and
  `X_Reed` for coordinates measured from the reed-seat datum.
- Use `Dia` for diameters and `OD`/`ID` only when the outside/inside
  distinction matters.

## Datums

| Datum | SolidWorks name | Meaning |
| --- | --- | --- |
| Bore axis | `DATUM_BORE_AXIS` | centerline of bore and turned body |
| Bell plane | `DATUM_BELL_FACE` | zero for `CLM_H##_X_Bell_in` |
| Reed seat plane | `DATUM_REED_SEAT` | zero for mouthpiece socket and reed reference |
| Front-hole plane | `DATUM_FRONT_HOLES` | angular plane for H01-H07 |
| Key side plane | `DATUM_KEY_SIDE` | angular plane for K02 and optional side levers |

## Core Variables

```text
CLM_SOS_in_per_s
CLM_Root_MIDI
CLM_Root_Hz
CLM_Bore_ID_in
CLM_Wall_T_in
CLM_Body_OD_in
CLM_Body_L_Final_in
CLM_Blank_L_in
CLM_Bell_OD_in
CLM_Mouthpiece_Socket_ID_in
CLM_Reed_Corr_in
CLM_Bell_End_Corr_in
```

## Repeated Hole Variables

```text
CLM_H01_X_Bell_in
CLM_H01_Dia_in
CLM_H01_Chimney_H_in
CLM_K01_X_Bell_in
CLM_K01_Dia_in
CLM_K01_Pad_OD_in
CLM_K01_Lever_L_in
```

## Configuration Table

Use `cad/solidworks-design-table.csv` as the seed table. In SolidWorks,
map the values either to global variables or to dimension names such as:

```text
CLM_Bore_ID_in@Sketch_Bore
CLM_Body_L_Final_in@Boss_Body
CLM_H01_X_Bell_in@Sketch_Holes
CLM_H01_Dia_in@Sketch_Holes
```

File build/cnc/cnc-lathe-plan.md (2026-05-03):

# CNC And Lathe Plan

## Preferred First Prototype Method

Use the lathe/drill-ream workflow for the soprano C prototype. The bore
is short enough that a solid blank is practical and easier to validate
than a split-blank glue-up.

## Operations

1. Square and center the blank.
2. Drill pilot bore from reed-seat end.
3. Step drill/ream to target bore ID.
4. Turn exterior cylinder and ornamental beads/collars.
5. Cut mouthpiece socket and bell tenon/socket.
6. Mark hole centers from bell datum using a V-block or rotary index.
7. Drill holes undersize on drill press or CNC with a cradle fixture.
8. Tune holes by hand reaming.
9. Add keywork post holes only after key lever geometry is confirmed.

## CNC Fixture Concept

- V-block cradle with two dowel pin datums.
- Bore axis parallel to X.
- Bell face against a fixed stop for `DATUM_BELL_FACE`.
- Rotary/indexing marks for front-hole plane and side-key plane.
- Use a peck cycle for clean hole walls; back up the bore with a
  removable mandrel if tearout appears.

## Tooling Notes

- Long drill bits must be checked for runout.
- Ream/lap the bore after drilling; do not rely on twist drill diameter.
- Keep tone-hole drills small for first pass and open by hand.
- For bass, consider split-blank routing if long drilling wanders.

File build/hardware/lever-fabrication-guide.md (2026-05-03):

# Handmade Chalumeau Lever Fabrication Guide

## Goal

Make small metal levers that behave like early woodwind keys: a spring
keeps a pad closed over a tone hole, and the player's finger presses a
touchpiece to open it.

## Recommended Prototype Materials

| Part | Prototype spec | Keeper-build upgrade |
| --- | --- | --- |
| Lever arm | 0.040-0.062 in brass strip | nickel silver strip |
| Pivot | 1/16 in brass rod or shoulder screw | hardened rod between turned posts |
| Posts | brass tube/rod, screwed or epoxied into body | silver-soldered post feet and screws |
| Spring | 0.012-0.018 in phosphor bronze wire | blued needle spring or flat spring |
| Pad cup | brass washer/cup soldered to arm | spun/soldered cup |
| Pad | cork with thin leather facing | clarinet-style skin pad |
| Regulation | cork/felt bumper | cork/felt plus adjustment screw |

## Simple K01/K02 Construction

1. Drill the keyed tone hole undersize and leave the rim proud enough to
   sand flat.
2. Turn or file a flat pad seat around the hole. A pad cannot seal on a
   lumpy collar.
3. Make a paper lever pattern. The touchpiece should sit under a natural
   finger motion, while the pad cup centers over the tone hole.
4. Cut the lever from brass strip. Round every player-facing edge.
5. Solder or rivet a small pad cup/washer to the pad end.
6. Drill the pivot hole. Ream until the lever rotates freely on the rod
   without side shake.
7. Mount two posts on the body. Use a drill guide so both post holes are
   square to the bore centerline.
8. Install the lever and spring. The default state for K01/K02 is pad
   closed; pressing the lever opens the tone hole.
9. Add cork or felt stops so the lever opens only 0.060-0.100 in beyond
   acoustic clearance.
10. Seat the pad with shellac or contact cement. Check with a leak light
    or suction test before tuning.

## Pad Geometry Rule

Pad OD should be the tone-hole diameter plus 0.080-0.125 in. The pad cup
should not hit the body before the pad compresses. Keep the pad travel
low; huge key lift feels sloppy and slows the action.

## Spring Options

- Flat spring: easiest for a first prototype. Screw or rivet one end to
  the lever/body and let the free end bias the lever closed.
- Needle spring: better action, but requires a spring cradle or post.
- Elastic/thread return: useful for a temporary test, not a final build.

## SolidWorks Modeling Notes

Model each key as a subassembly:

- `Key_K01_Lever`
- `Key_K01_Post_A`
- `Key_K01_Post_B`
- `Key_K01_Pad`
- `Key_K01_Spring`

Mate the lever concentric to `CLM_Key_Pivot_Rod_Dia_in`. Add an angular
limit mate for closed/open positions. Keep pad compression as an
explicit variable, not an accidental interference.

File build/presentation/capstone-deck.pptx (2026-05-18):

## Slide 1

Chalumeau Family Capstone

- Musical instrument documentation capstone
- Build packet: chalumeau
- Generated: 2026-05-03

Slide 1

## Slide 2

Project Intent

- Design a family of chalumeaux that can be built in Tony's shop using
- lathe/CNC workflows, commercial reeds for early isolation tests, and
- optional handmade metal keywork. The family should cover a useful range
- without pretending the first-pass physics is final: all tone-hole
- coordinates are starting points that must be validated with a real reed,
- mouthpiece, bore, and player pressure.

Slide 2

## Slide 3

Physics Model

- The chalumeau is modeled as a cylindrical single-reed pipe that behaves
- like a stopped pipe in its low register.
- f = c / (4 * L_eff)
- L_eff = c / (4 * f)
- c = 13552 in/s at about 68 F
- body_length = L_eff - bell_end_correction - reed_end_correction
- bell_end_correction = 0.61 * bore_radius

Slide 3

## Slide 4

Hardware Alignment

- The hardware is intentionally small-shop manufacturable:

Slide 4

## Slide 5

How To Use This Packet

- Start with ../packet/design.md for intent and assumptions.
- Use ../packet/bom.csv, ../packet/sourcing.csv, and ../packet/cut-list.csv before buying or cutting.
- Use ../packet/drawing-brief.md and CAD/CNC folders before machining.
- Print the packet for shopping, shop work, and validation.

Slide 5

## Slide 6

File Map

- ../packet/design.md: Project intent, catalog metadata, assumptions, and validation plan.
- ../packet/bom.csv: Starter bill of materials with part categories, quantities, drawing refs, and notes.
- ../packet/sourcing.csv: Supplier/search tracker with specs, price/date fields, lead time, substitutes, and risks.
- ../packet/cut-list.csv: Rough/final stock sizes, material, grain/orientation, operations, yield, and offcuts.
- ../packet/drawing-brief.md: Manufacturing drawing and technical product sketch brief.
- ../packet/assembly-manual.md: Shop-facing sequence, tools, fixtures, safety, tuning, finishing, and maintenance notes.
- ../packet/validation.csv: Target/measured values, tolerance, environment, result, and tuning/build action log.

Slide 6

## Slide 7

Family Spec

Slide 7

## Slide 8

Build Workflow

- Design and assumptions
- Source materials and hardware
- Prepare stock, fixtures, and CNC/laser/lathe setup
- Assemble, tune, finish, and validate

Slide 8

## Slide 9

Sourcing And BOM

- BOM gives part categories and drawing references.
- Sourcing tracks search terms, supplier candidates, price/date, lead time, substitutions.
- Visual BOM brief turns the parts list into a presentation-ready image board.

Slide 9

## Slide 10

Shop Packet

- Cut list for lumber/sheet/blank planning.
- Assembly manual for away-from-keyboard work.
- Validation sheet for measured dimensions, tuning, pass/fail checks.

Slide 10

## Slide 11

Drawings, CAD, CNC

- ../packet/drawing-brief.md defines required views, dimensions, datums, sketch intent.
- ../cad/ holds models and design tables.
- ../cnc/ holds CAM, toolpaths, setup sheets, dry-run notes.
- ../drawings/ holds PDFs, SVGs, DXFs, drawing exports.
- ![drawing](../drawings/chalumeau-family-sheet.svg)
- ![drawing](../drawings/chalumeau-soprano-c4-dimensioned.svg)
- ![drawing](../drawings/keywork-lever-detail.svg)

Slide 11

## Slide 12

Images And Screenshots

- ../../assets/images/chalumeau1.jpg
- ../../assets/images/chalumeau5.jpg
- ![image](../../assets/images/chalumeau1.jpg)
- ![image](../../assets/images/chalumeau5.jpg)

Slide 12

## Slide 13

Validation Plan

- A4 = 440 Hz reference check.
- Tuning targets logged in validation.csv.
- Critical dimensions verified against design sheet and CAD.
- Photos and revision notes after each major step.

Slide 13

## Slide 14

Open Risks / Decisions

- TBDs in design sheet and BOM.
- Supplier price/availability not yet verified.
- Generated images marked as concept placeholders.
- Empirical corrections await measured prototype data.

Slide 14

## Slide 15

Next Actions

- Replace TBDs with measured/source-backed values.
- Verify live supplier price and availability before buying.
- Export final drawings and visual BOM images.
- Regenerate this deck and print packet after final edits.

Slide 15

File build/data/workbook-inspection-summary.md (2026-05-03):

# Workbook Inspection Summary

Inspected workbook:

`C:/Users/Tony/Documents/Claude/Projects/Career/flutes-staging/Musical Instruments.xlsx`

Relevant source sheet:

`Great Highland Bagpipe`

Useful starting points found:

- Chanter rows document conical double-reed behavior and show why
  conical reed instruments should not be treated exactly like flutes.
- Drone rows use a cylindrical single-reed stopped-pipe model
  `f = c/(4L)`, which is closer to the chalumeau boundary condition.
- Reed rows emphasize buying/commercial reeds first, because reed-making
  skill can mask bore-design errors.
- Wood rows suggest a sensible prototype sequence: cherry/walnut/maple
  first, ipe/cocobolo/boxwood/dense woods later.

Applied decision:

The chalumeau packet uses a stopped cylindrical single-reed model and a
validation-first tone-hole schedule. It does not import Native American
flute K2 corrections or bagpipe chanter conical-bore dimensions.

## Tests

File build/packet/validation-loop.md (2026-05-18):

# Chalumeau Prototype Validation Loop

This loop keeps the current chalumeau packet at prototype readiness until
real measurements prove the reed, mouthpiece, bore, tone holes, and player
response. CAD tables, drawings, and generated visuals are planning aids until
their dimensions are reconciled with measured shop data.

## Gate Summary

| Gate | Evidence file | Pass condition | Blocks |
| --- | --- | --- | --- |
| P0 reed/mouthpiece setup | `../data/reed-mouthpiece-capture-template.csv` | one stable `reed_id` and `mouthpiece_id` chosen, with onset and response notes recorded | root pitch claims |
| P1 bore/root tuning | `../data/bore-trim-capture-template.csv` | bore stations measured, datum confirmed, leak status recorded, all-closed C4 within +/- 15 cents before final tuning | final tone-hole drilling |
| P2 tone-hole tuning | `../data/tuning-capture-template.csv` | H01-H07 measured with same `reed_id`, `mouthpiece_id`, and `bore_profile_id`; final rows within +/- 12 cents and response rating >= 3 | family scaling |
| P3 keywork seal | `validation.csv` plus build photos or leak notes | K01/K02 pads pass leak-light or suction check before pitch rows are trusted | keyed-note claims |
| P4 scale-up decision | revised design table or correction notes | empirical correction is documented from P1/P2 before alto, tenor, or bass dimensions are promoted | larger-family builds |

## P0 - Reed And Mouthpiece Setup

1. Choose a commercial reed and mouthpiece for the first soprano C test.
2. Assign stable IDs such as `REED-001` and `MP-001`.
3. Record reed strength, soak state, mouthpiece facing if known, ligature,
   mouthpiece-only pitch/response, onset pressure, leak status, response
   rating, and any chirp/squeak behavior in
   `../data/reed-mouthpiece-capture-template.csv`.
4. Use the same IDs in the bore and tuning logs. If either changes, start a
   new `session_id` instead of mixing measurements.

## P1 - Bore And Root Tuning

1. Measure the bore at the reed seat, mid-bore, and bell face before tone-hole
   layout.
2. Record body length before every trim, body length after every trim, and the
   all-closed measured frequency in `../data/bore-trim-capture-template.csv`.
3. Treat the all-closed root as provisional until the reed response is stable.
4. Do not drill final tone-hole diameters until the datum, bore, and root row
   are internally consistent.

## P2 - Tone-Hole Tuning

1. Drill holes 15-25 percent undersize.
2. Tune from the bell upward, logging each diameter change and measured
   frequency in `../data/tuning-capture-template.csv`.
3. Keep `dynamic_level` consistent, starting with `mp`, so pitch rows compare
   like with like.
4. If response drops below `3` on the 1-5 scale, fix leak, reed, or hole
   behavior before treating cents error as a geometry problem.

## P3 - Keywork And Register Experiments

K01 and K02 are allowed only after the keyless low register speaks reliably.
Record leak-light or suction results in `validation.csv` before trusting keyed
pitch rows. The register vent remains experimental and should be documented as
response research, not a first-build pass/fail requirement.

## Claim Boundary

Until P0-P2 contain measured data, this repo should describe the chalumeau as a
first-pass prototype packet with validation templates. Do not call it
build-ready, L3, L4, empirically tuned, or production-ready until the measured
logs and revised authority tables support those claims.

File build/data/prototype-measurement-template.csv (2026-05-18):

build_id | date | session_id | variant | body_serial | reed_id | mouthpiece_id | bore_profile_id | temperature_f | humidity_pct | a4_reference_hz | hole_state | target_note | target_hz | measured_hz | cents_error | response_rating_1_5 | onset_pressure_in_h2o | dynamic_level | leak_status | pass_condition | blocking_unknowns | action_taken | next_cut_or_hole_change | notes
CLM-SOP-C4-P1 |  | CLM-SOP-C4-P1-S01 | Soprano C | CLM-SOP-C4-BODY-001 | REED-001 | MP-001 | BORE-001 |  |  | 440 | all closed | C4 | 261.63 |  |  |  | mp | unknown | root measured within +/- 15 cents before final tone-hole tuning | reed/mouthpiece setup, bore profile, measured root pitch, response
CLM-SOP-C4-P1 |  | CLM-SOP-C4-P1-S01 | Soprano C | CLM-SOP-C4-BODY-001 | REED-001 | MP-001 | BORE-001 |  |  | 440 | K01 | C#4 | 277.18 |  |  |  | mp | unknown | keyed note measured after leak-light or suction pass | pad seal, measured keyed pitch, response
CLM-SOP-C4-P1 |  | CLM-SOP-C4-P1-S01 | Soprano C | CLM-SOP-C4-BODY-001 | REED-001 | MP-001 | BORE-001 |  |  | 440 | H01 | D4 | 293.66 |  |  |  | mp | unknown | tone hole measured within +/- 12 cents after final enlargement | measured pitch, final hole diameter, response
CLM-SOP-C4-P1 |  | CLM-SOP-C4-P1-S01 | Soprano C | CLM-SOP-C4-BODY-001 | REED-001 | MP-001 | BORE-001 |  |  | 440 | H02 | E4 | 329.63 |  |  |  | mp | unknown | tone hole measured within +/- 12 cents after final enlargement | measured pitch, final hole diameter, response
CLM-SOP-C4-P1 |  | CLM-SOP-C4-P1-S01 | Soprano C | CLM-SOP-C4-BODY-001 | REED-001 | MP-001 | BORE-001 |  |  | 440 | H03 | F4 | 349.23 |  |  |  | mp | unknown | tone hole measured within +/- 12 cents after final enlargement | measured pitch, final hole diameter, response
CLM-SOP-C4-P1 |  | CLM-SOP-C4-P1-S01 | Soprano C | CLM-SOP-C4-BODY-001 | REED-001 | MP-001 | BORE-001 |  |  | 440 | H04 | G4 | 392.0 |  |  |  | mp | unknown | tone hole measured within +/- 12 cents after final enlargement | measured pitch, final hole diameter, response
CLM-SOP-C4-P1 |  | CLM-SOP-C4-P1-S01 | Soprano C | CLM-SOP-C4-BODY-001 | REED-001 | MP-001 | BORE-001 |  |  | 440 | H05 | A4 | 440.0 |  |  |  | mp | unknown | tone hole measured within +/- 12 cents after final enlargement | measured pitch, final hole diameter, response
CLM-SOP-C4-P1 |  | CLM-SOP-C4-P1-S01 | Soprano C | CLM-SOP-C4-BODY-001 | REED-001 | MP-001 | BORE-001 |  |  | 440 | K02 | Bb4 | 466.16 |  |  |  | mp | unknown | keyed note measured after leak-light or suction pass | pad seal, measured keyed pitch, response
CLM-SOP-C4-P1 |  | CLM-SOP-C4-P1-S01 | Soprano C | CLM-SOP-C4-BODY-001 | REED-001 | MP-001 | BORE-001 |  |  | 440 | H06 | B4 | 493.88 |  |  |  | mp | unknown | tone hole measured within +/- 12 cents after final enlargement | measured pitch, final hole diameter, response
CLM-SOP-C4-P1 |  | CLM-SOP-C4-P1-S01 | Soprano C | CLM-SOP-C4-BODY-001 | REED-001 | MP-001 | BORE-001 |  |  | 440 | H07 | C5 | 523.25 |  |  |  | mp | unknown | tone hole measured within +/- 12 cents after final enlargement | measured pitch, final hole diameter, response

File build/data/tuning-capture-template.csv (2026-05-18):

session_id | date | variant | body_serial | reed_id | mouthpiece_id | bore_profile_id | hole_id | hole_state | drilling_stage | hole_dia_before_in | hole_dia_after_in | target_note | target_hz | measured_hz | cents_error | response_rating_1_5 | onset_pressure_in_h2o | dynamic_level | leak_check_result | pass_condition | blocking_unknowns | action_taken | next_cut_or_hole_change | notes
CLM-SOP-C4-P1-S01 |  | Soprano C | CLM-SOP-C4-BODY-001 | REED-001 | MP-001 | BORE-001 | ROOT | all closed | root trim |  |  | C4 | 261.63 |  |  |  | mp | unknown | measured within +/- 15 cents before final tone-hole tuning | reed/mouthpiece setup, bore profile, root measured_hz, response
CLM-SOP-C4-P1-S01 |  | Soprano C | CLM-SOP-C4-BODY-001 | REED-001 | MP-001 | BORE-001 | K01 | K01 | undersize-to-final |  | 0.160 | C#4 | 277.18 |  |  |  | mp | unknown | pad seals and keyed note response is rated >= 3 before pitch is accepted | leak result, measured_hz, response
CLM-SOP-C4-P1-S01 |  | Soprano C | CLM-SOP-C4-BODY-001 | REED-001 | MP-001 | BORE-001 | H01 | H01 | undersize-to-final |  | 0.180 | D4 | 293.66 |  |  |  | mp | unknown | final measured pitch within +/- 12 cents with response >= 3 | measured_hz, cents_error, response, final diameter
CLM-SOP-C4-P1-S01 |  | Soprano C | CLM-SOP-C4-BODY-001 | REED-001 | MP-001 | BORE-001 | H02 | H02 | undersize-to-final |  | 0.190 | E4 | 329.63 |  |  |  | mp | unknown | final measured pitch within +/- 12 cents with response >= 3 | measured_hz, cents_error, response, final diameter
CLM-SOP-C4-P1-S01 |  | Soprano C | CLM-SOP-C4-BODY-001 | REED-001 | MP-001 | BORE-001 | H03 | H03 | undersize-to-final |  | 0.170 | F4 | 349.23 |  |  |  | mp | unknown | final measured pitch within +/- 12 cents with response >= 3 | measured_hz, cents_error, response, final diameter
CLM-SOP-C4-P1-S01 |  | Soprano C | CLM-SOP-C4-BODY-001 | REED-001 | MP-001 | BORE-001 | H04 | H04 | undersize-to-final |  | 0.190 | G4 | 392.00 |  |  |  | mp | unknown | final measured pitch within +/- 12 cents with response >= 3 | measured_hz, cents_error, response, final diameter
CLM-SOP-C4-P1-S01 |  | Soprano C | CLM-SOP-C4-BODY-001 | REED-001 | MP-001 | BORE-001 | H05 | H05 | undersize-to-final |  | 0.200 | A4 | 440.00 |  |  |  | mp | unknown | final measured pitch within +/- 12 cents with response >= 3 | measured_hz, cents_error, response, final diameter
CLM-SOP-C4-P1-S01 |  | Soprano C | CLM-SOP-C4-BODY-001 | REED-001 | MP-001 | BORE-001 | K02 | K02 | undersize-to-final |  | 0.150 | Bb4 | 466.16 |  |  |  | mp | unknown | pad seals and keyed note response is rated >= 3 before pitch is accepted | leak result, measured_hz, response
CLM-SOP-C4-P1-S01 |  | Soprano C | CLM-SOP-C4-BODY-001 | REED-001 | MP-001 | BORE-001 | H06 | H06 | undersize-to-final |  | 0.170 | B4 | 493.88 |  |  |  | mp | unknown | final measured pitch within +/- 12 cents with response >= 3 | measured_hz, cents_error, response, final diameter
CLM-SOP-C4-P1-S01 |  | Soprano C | CLM-SOP-C4-BODY-001 | REED-001 | MP-001 | BORE-001 | H07 | H07 | undersize-to-final |  | 0.160 | C5 | 523.25 |  |  |  | mp | unknown | final measured pitch within +/- 12 cents with response >= 3 | measured_hz, cents_error, response, final diameter

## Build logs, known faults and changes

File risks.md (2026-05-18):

# Chalumeau Bare-Bones Risk Register

Current status: **bare-bones readiness packet / L2 scaffold**.

This root risk register is intentionally conservative. It records what can go
wrong before the first measured soprano prototype, and it does not treat
generated tables, SVG previews, or source CAD as fabrication authority.

| Risk ID | Area | Risk | Why it matters | Mitigation / next test |
| --- | --- | --- | --- | --- |
| R-BB-001 | Acoustics | Reed and mouthpiece compliance shift the effective pipe length. | A first-pass stopped-pipe model can be wrong if the reed setup is unstable. | Select one commercial reed/mouthpiece setup and record it with every measurement. |
| R-BB-002 | Tuning | Tone-hole positions and diameters are derived estimates. | Oversized holes cannot be made smaller without repair. | Drill undersized, tune gradually, and log measured cents error in a prototype pass. |
| R-BB-003 | Boundary conditions | NAF or open-flute corrections could be misapplied. | Wrong acoustic law would make the schedule misleading. | Keep chalumeau labeled as cylindrical single-reed stopped pipe until measurement proves corrections. |
| R-BB-004 | Keywork | Handmade K01/K02 pads may leak or bind. | Leaks can make tuning data useless and response unreliable. | Validate keyless body first; then leak-light/suction-test each key before pitch logging. |
| R-BB-005 | Fabrication | CAD/OpenSCAD/SVG artifacts may be mistaken for reviewed fabrication authority. | Starter geometry can propagate unvalidated dimensions to the shop. | Declare the authority artifact only after CAD/DXF/design-table review and measured prototype feedback. |
| R-BB-006 | Materials | Dense or oily woods may crack, move, or complicate machining. | Keeper-build wood can hide process errors and introduce health hazards. | Prototype in domestic hardwood first; treat dense woods as later substitutions requiring dust/finish checks. |
| R-BB-007 | Sourcing | Supplier prices, availability, and reed compatibility are not live-checked. | Stale sourcing can derail the first build or force geometry changes. | Recheck sourcing at purchase time and record substitutions. |
| R-BB-008 | Documentation | Attributed reference photos could be mistaken for Tony build photos. | Public readers need provenance clarity. | Keep captions explicit and replace with Tony-built prototype photos when available. |

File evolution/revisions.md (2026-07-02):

# Revision Register — chalumeau

| Rev | Date | Parent | Delta | Downstream artifacts invalidated |
| --- | --- | --- | --- | --- |
| A | 2026-07-01 | — | Stage 0 intake of current masters (cad/chalumeau.scad + build/packet/family-spec.csv + build/data/tone-hole-schedule.csv). | none (no alpha/beta/production artifacts exist yet) |

Stage 0 only. Gate A has not been run; no Alpha compiles, vendor quotes, or production lock exist for this product.

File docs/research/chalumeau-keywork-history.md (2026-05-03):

# Chalumeau Keywork: Why Some Have Levers And Some Do Not

## Short Answer

Keyless chalumeaux are the simple form: a cylindrical single-reed pipe
with finger holes placed where human fingers can reach them. Levers or
keys appear when the maker wants a hole that is too far away, too large,
too awkward to seal, or useful for a chromatic note. The clarinet
evolved from this same family by making one of those keys work as a
real register/speaker vent and then adding more keys for chromatic
notes, low extensions, trills, and improved intonation.

## Historical Logic

Britannica describes the chalumeau as a cylindrical single-reed stopped
pipe and says Johann Christoph Denner added an extra finger hole and two
keys around 1700, with later experimentation leading to the clarinet.
It also notes that the chalumeau did not overblow into a register above
the fundamental the way the clarinet does.

Gregory Barrett's NIU clarinet history gives the design distinction in
practical terms: the chalumeau was optimized for the low chalumeau
register, while the early clarinet moved the back key higher and made it
smaller so it functioned as a register/speaker key. On a cylindrical
closed-pipe instrument, that register key produces notes a twelfth above
the low-register fingering, not an octave above.

The Baltimore Recorders chalumeau note makes the same point from the
instrument-layout side: the chalumeau's two uppermost keys are placed
differently from the clarinet's register key, which is why a chalumeau
remains mostly a low-register instrument.

## What The Levers Do

- Open a tone hole that is outside direct finger reach.
- Close or open a hole that is too large for a fingertip to seal.
- Add chromatic notes without awkward cross-fingering.
- Improve tuning by putting the acoustically correct hole where the
  hand cannot comfortably go.
- On clarinets, act as a register/speaker vent so the cylindrical bore
  overblows by a twelfth.
- On later clarinets, link multiple holes so one finger can operate a
  pad somewhere else on the body.

## Design Choice For This Project

Build the first soprano C chalumeau keyless so the bore, reed, and
seven-hole scale can be debugged cleanly. Then add two handmade
normally closed keys:

- `K01`: a low semitone key near the bell.
- `K02`: an upper chromatic side key.

Treat the clarinet-style register vent as a later experiment, because a
vent hole drilled too early can compromise the low-register chalumeau.

## Sources

- Britannica, "chalumeau": https://www.britannica.com/art/chalumeau
- Britannica, "clarinet": https://www.britannica.com/art/clarinet
- Gregory Barrett, Northern Illinois University, "Development of the Clarinet": https://www.niu.edu/gbarrett/resources/development.shtml
- Baltimore Recorders, "about the Chalumeau": https://www.baltimorerecorders.org/html/instruments/chalumeau.html

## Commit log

2026-05-03 codex skill instrument maker v3
    chalumeau
    [bom.csv, chalumeau-family-design-table.xlsx, chalumeau_family_master.scad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]
2026-05-18 Add chalumeau bare-bones starter packet (#3)
    * Add chalumeau bare-bones starter packet
    * Fix chalumeau packet diff hygiene
    ---------
    [bom.csv, validation.csv]
2026-05-18 Add chalumeau validation capture loop (#2)
    * Add chalumeau validation capture loop
    * Refresh chalumeau presentation exports
    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
    [bore-trim-capture-template.csv, prototype-measurement-template.csv, reed-mouthpiece-capture-template.csv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]
2026-05-18 Add chalumeau measurement capture gates (#4)
    [bore-trim-capture-template.csv, family-spec.csv, prototype-measurement-template.csv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]
2026-05-30 v5-migrate(chalumeau): register + mcp-log + status (Refs instrument-maker#184) (#5)
    [visual-output-register.csv]
2026-05-31 Add image-gen concept prompt; wire explorer images
2026-06-21 Wire 2 rendered concept image(s) into explorer gallery
2026-07-02 V5 packet refresh: status line, provenance, parametric OpenSCAD master, evolution intake
    - Baseline validator (validate_v5_packet_fixed.py): 3 failures -> 0 failures
    (missing root sourcing.csv/cut-list.csv/drawing-brief.md scaffolded honestly,
    TBD-marked, condensed from existing build/packet/ equivalents). 13 WARNs
    remain, all "unknown authority value 'pending_measurement'" -- expected per
    V5 standard, left as-is.
    - New codeCAD master cad/chalumeau.scad: parametric bore-envelope +
    tone-hole-schedule OpenSCAD model for the soprano/alto/tenor/bass family,
    values traced to build/packet/family-spec.csv and
    build/data/tone-hole-schedule.csv. Mouthpiece, reed, reed-seat/tenor
    socke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
    [chalumeau.scad, cut-list.csv, sourcing.csv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]
